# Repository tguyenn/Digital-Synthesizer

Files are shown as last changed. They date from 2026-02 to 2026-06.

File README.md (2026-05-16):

# Imagiano | Digital Synthesizer Project

## $$\color{#CC5500} \text{UT ECE445L Competition Project}$$

Brought to you by...    
[@jeffchang0](https://github.com/jeffchang0)    
[@MorrisYLin](https://github.com/MorrisYLin)    
[@zaarabilal](https://github.com/zaarabilal)    
[@tguyenn](https://github.com/tguyenn)    

## Introduction

We decided to build a digital synthesizer/piano for our final project in UT Austin's Embedded Lab Class! We thought a piano was a great idea since we all love music, and a digital synthesizer presented a good deal of electrical, mechanical, and programming challenges.
  
Our digital piano consists of    
1.) A main controller board  
2.) A series of peripheral boards  
3.) Piano keys with magnets  
4.) Piano enclosure     
    
... all from scratch!  
  
Here's a clip of our project (Rev A) in action, credit to [@jeffchang0](https://github.com/jeffchang0):
> [!IMPORTANT]
> Please <ins>__enable audio__</ins> and applaud the ~~mouth~~camerawork for the full demonstration!  

<p align="center">
  <video src="https://github.com/user-attachments/assets/4a25433e-0272-4781-a5fd-c7f0d65e424b" width="300" controls>
  </video>
</p>

## Table of Contents
1. [System Design](#system-design)
1. [Electrical Design](#electrical-design)
1. [Mechanical Design](#mechanical-design)
1. [Firmware Design](#firmware-design)
1. [Implementation Challenges](#implementation-challenges)
1. [Rev A Credits](#rev-a-credits)
1. [Rev B Motivation and Features](#rev-b-motivation-and-features)

## System Design
Figuring out requirements is by far the most important part of a project! Of course you have to know what you are building before you build it :)

We knew we wanted to make a piano of a larger scale, so we had to figure out how to seamlessly connect a lot of keys together.

After some thinking and debate, we came down to this diagram for our overall system design:    

We opted to have a main controller board daisy-chained with a series of peripheral boards. This main board would also be connected to user interfaces like an LCD, digital rotary encoders, and an addressable LED strip.        

<table>
  <tr>
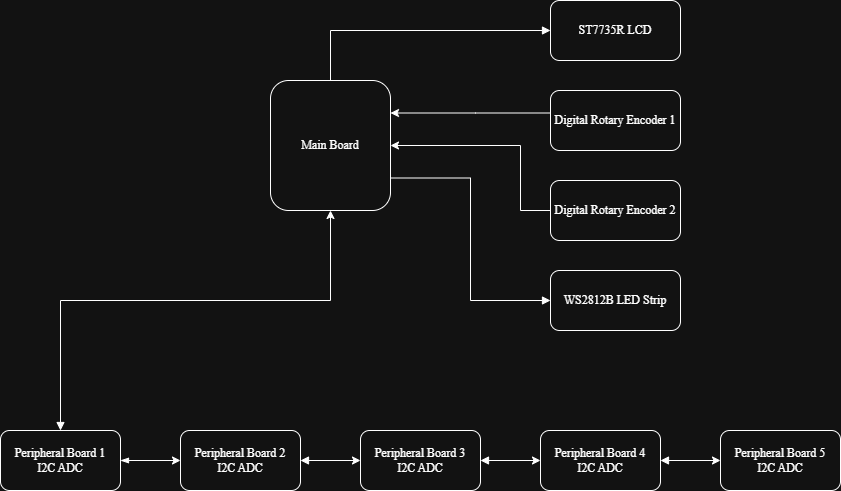
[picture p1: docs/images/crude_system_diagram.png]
system plan diagram
    <td></td>
  </tr>
  <tr>
    <td colspan="1" align="center">
      <em><b></b> System Plan Diagram</em>
    </td>
  </tr>
</table>  
Each peripheral board would have an array of linear Hall effect sensors to determine key position, with 12 of these sensors to form an octave. 5 of these peripheral boards allowed us to cover a good range of pitches!  
       
<table>
  <tr>
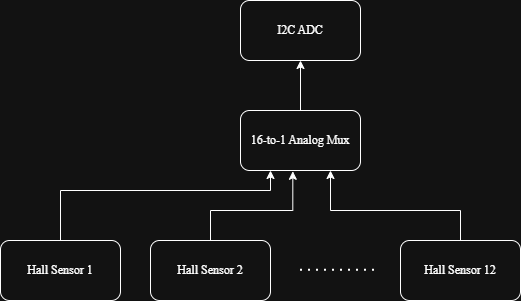
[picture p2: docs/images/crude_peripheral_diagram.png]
periph board diagram
    <td></td>
  </tr>
  <tr>
    <td colspan="1" align="center">
      <em><b></b> Peripheral Board Plan Diagram</em>
    </td>
  </tr>
</table>

To give some insight into what this came to be, here is a picture of our daisy-chained peripheral boards (sharpie for scale):  
<table>
  <tr>
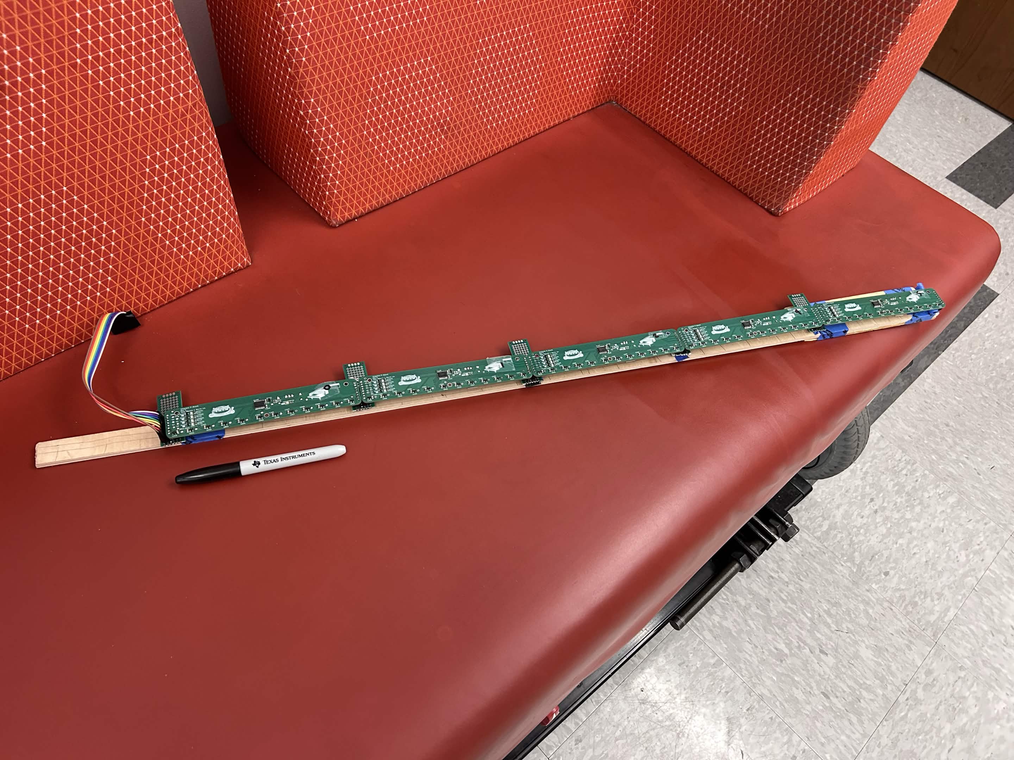
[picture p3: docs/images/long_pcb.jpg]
long pcb
    <td></td>
  </tr>
  <tr>
    <td colspan="1" align="center">
      <em><b></b> Extra Extra Long PCB</em>
    </td>
  </tr>
</table>

## Electrical Design
Once we had planned out the high-level details of the project, it was time to figure out what electrical connections needed to be made. First, it was time to go window shopping and datasheet diving on Mouser to figure out what we were even working with.

Once we had picked out all our parts, we drew out the schematic (and all of the relevant subsheets):    

<table>
  <tr>
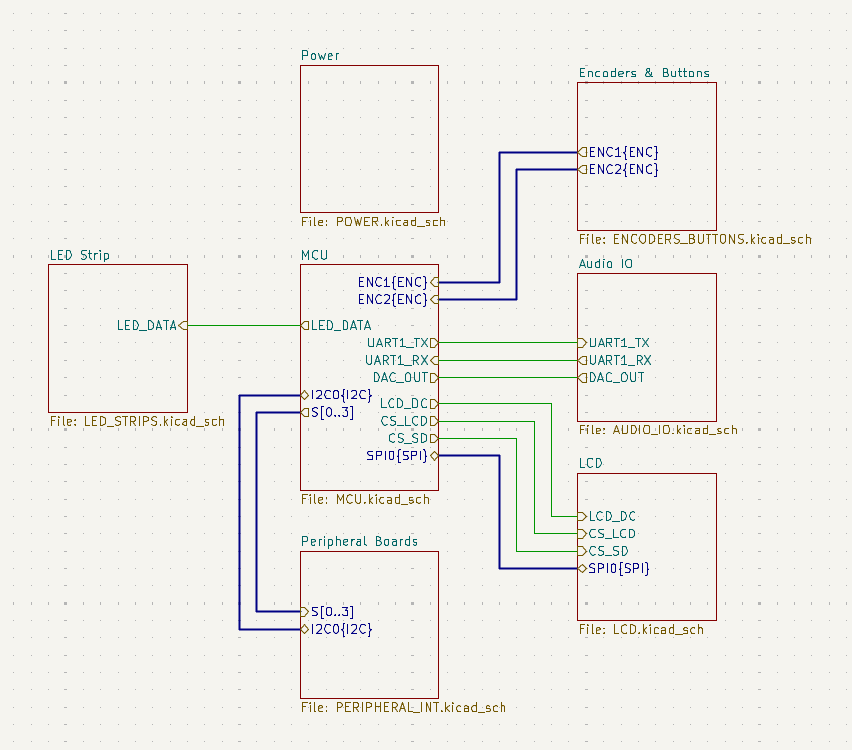
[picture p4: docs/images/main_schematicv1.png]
Main Schematic Rev A
    <td></td>
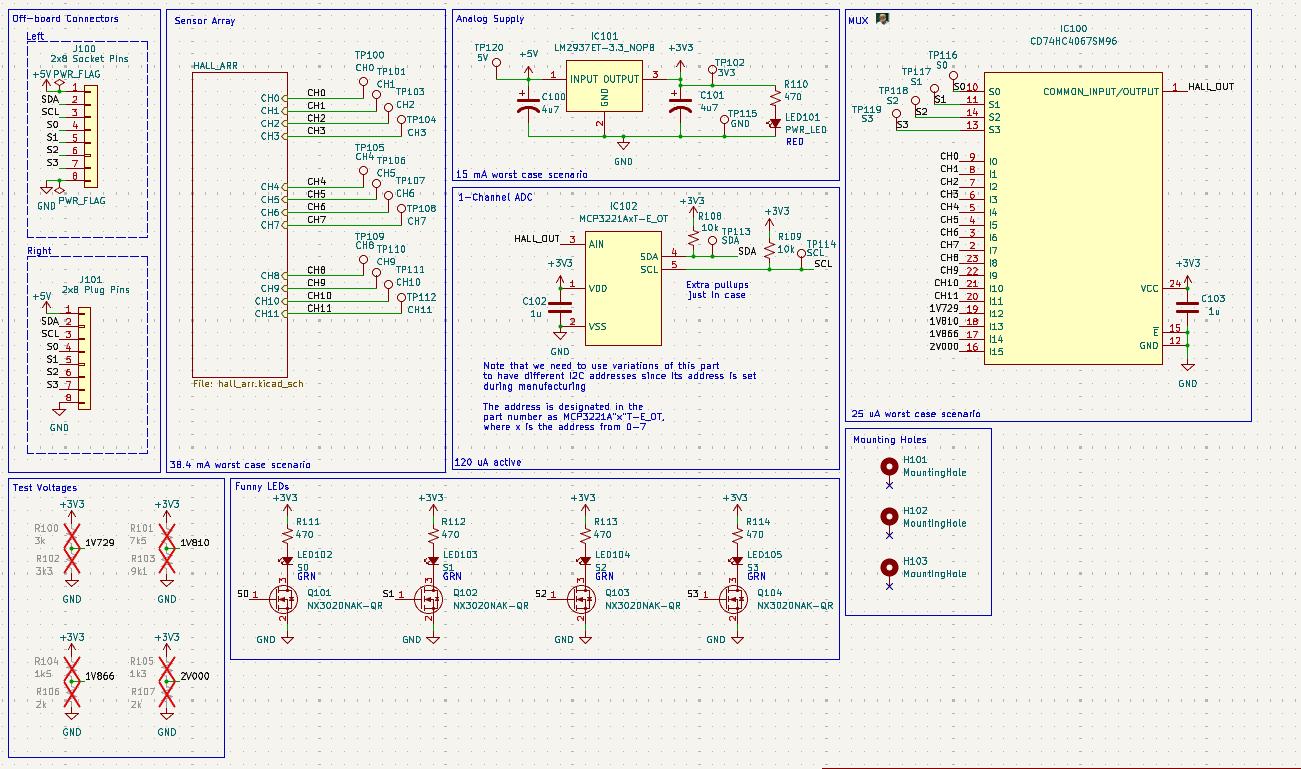
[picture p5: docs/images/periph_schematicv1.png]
Periph Schematic Rev A
    <td></td>
  </tr>
  <tr>
    <td colspan="2" align="center">
      <em><b>Rev A -</b>  Main (Left) and Peripheral (Right) Schematics</em>
    </td>
  </tr>
</table>

After verifying the schematic, we moved onto laying out the PCB itself:
<table>
  <tr>
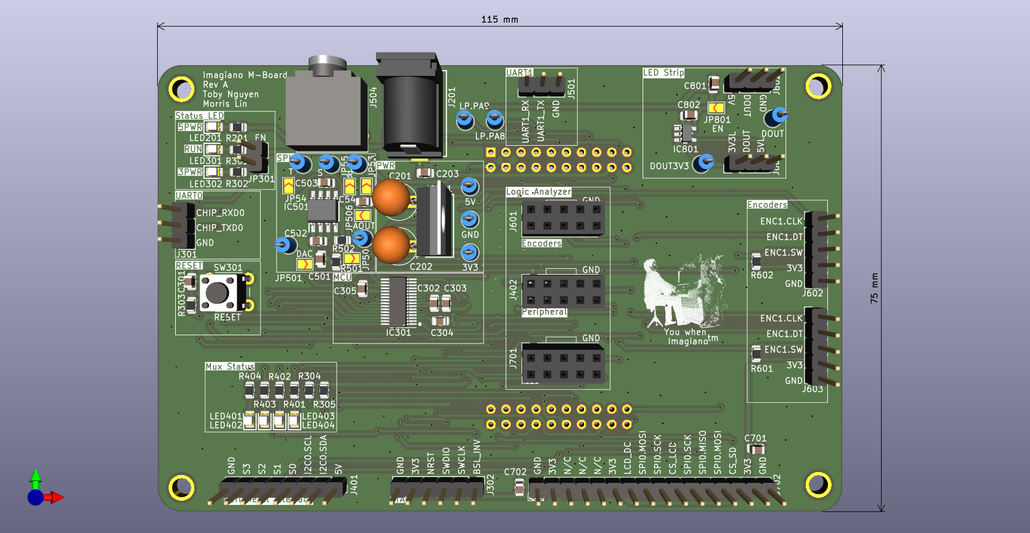
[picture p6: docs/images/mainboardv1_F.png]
    <td></td>
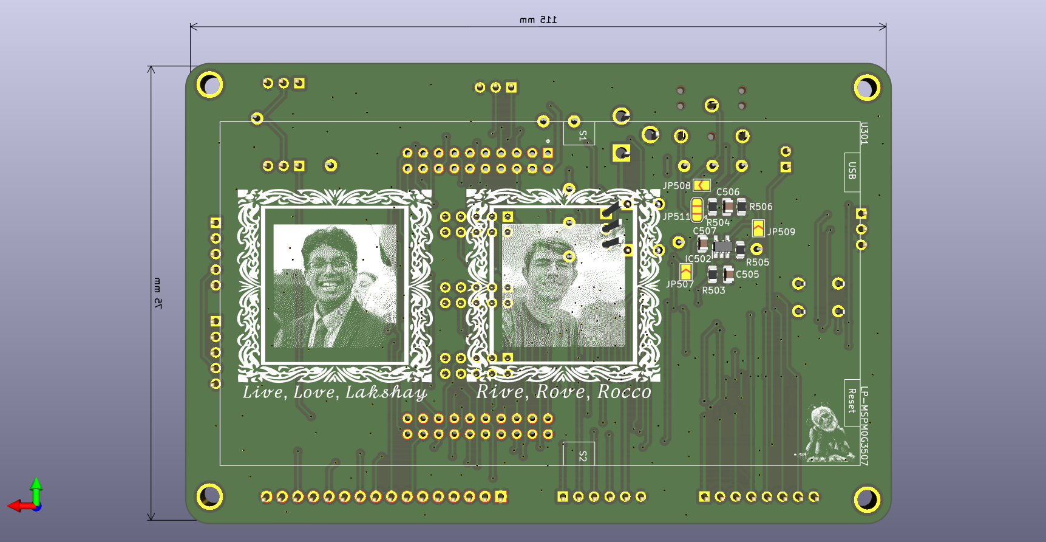
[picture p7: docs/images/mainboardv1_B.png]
    <td></td>
  </tr>
  <tr>
    <td colspan="2" align="center">
      <em><b>Rev A -</b> Front and back main board</em>
    </td>
  </tr>
</table>

<table>
  <tr>
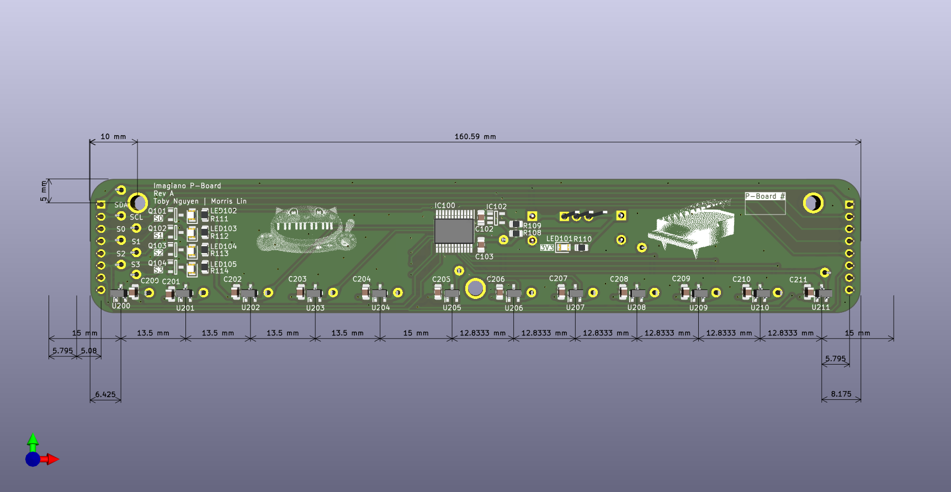
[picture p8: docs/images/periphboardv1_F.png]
    <td></td>
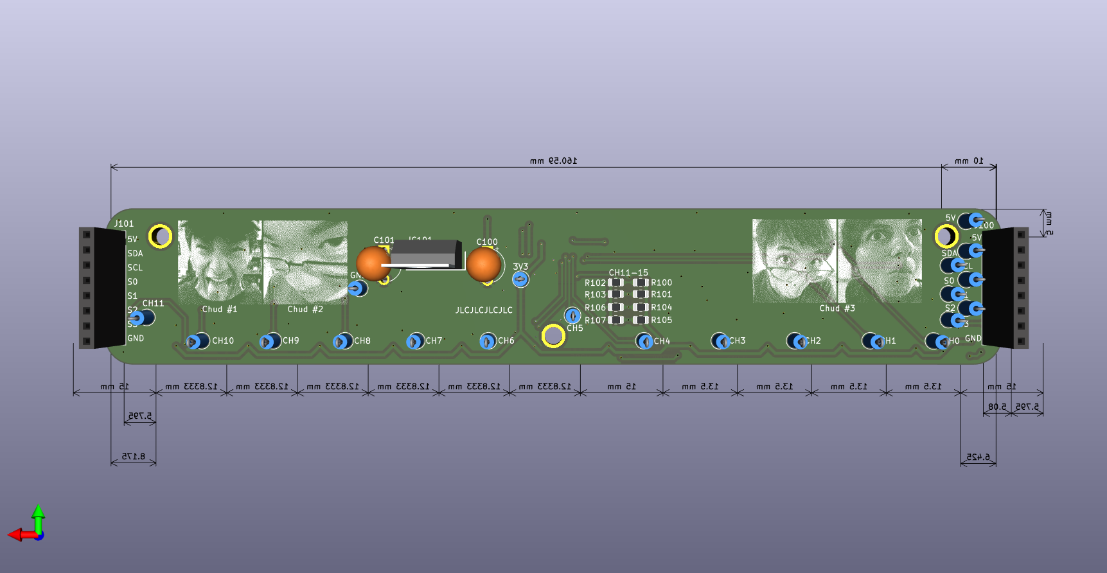
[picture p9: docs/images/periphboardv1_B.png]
    <td></td>
  </tr>
  <tr>
    <td colspan="2" align="center">
      <em><b>Rev A -</b> Front and back peripheral board</em>
    </td>
  </tr>
</table>

### Design Choices
#### Why did you choose Texas Instrument's MSPM0G3507 MCU?
- Since this was a class project, we were required to use this particular MCU.

#### Why did you use an MSPM0G3507 launchpad/devkit instead of having two discrete MCUs?
- Since this was a class project, we were required to have a fallback plan in case our discrete MCU did not work for any reason.  

#### Why did you choose I2C over SPI for the wired peripheral board bus?
- At first we were going to go with an SPI bus connected as a "star topology" vs daisy-chained. We ultimately went with I2C to reduce the amount of GPIO usage and wires (i.e. SPI CS line for every peripheral board -> just the I2C SDA & SCL). We did consider the possible issue of bus capacitance since our bus would be almost a meter long (!!), but we just accepted our fate (reduce I2C speed if necessary).  

#### Why is there an LDO on every peripheral board?
- Instead of routing 3V3 all across each peripheral board, we opted to route 5V and have local 3V3 LDOs. This removed any possibility of power supply noise within our sensitive analog Hall sensors.  

#### Why do we have LEDs on the analog mux select lines?
- For fun! It's also nice to have a visual indicator when debugging (i.e. which sensor index is being sampled right at this moment when I pause?)  

#### Why did you use a mix of through hole components (LDO, capacitors) or other non-ideal components (speaker amp)?
- Since this was a class project, we were restricted to a very stringent budget ($60!) for the entire project. The through hole components and speaker amp were considered "free" since we could get them from a university equipment desk.    

#### Why did you use funny protoboards as connectors instead of using right angle connectors?
- Same thing as above. Right angle connectors would be the way to go, but the budget limitations said otherwise.    
  
#### Why did you choose a 2 layer PCB?
- 4 layers would be overkill for this project since board density wasn't crazy. This was also a school project, so we didn't need to worry about EMC regulations (RIP ground plane) and had to worry more about the budget.

#### What happened for your speaker output circuit?
- At the last minute (literally like an hour before designs were due) we realized our original amp design could potentially not work (slipped through team and TA design review), so we slapped on a backup circuit (simple voltage buffer) on the other side. The particular issue was our questionable adaptation of a (free!) differential amplifier for a single ended application.

## Mechanical Design

TODO: @jeffchang0 cad models pictures?

TODO: @jeffchang0 mechanical design challenges

TODO: talk about mass manufacturing of keys
    - shoutout "tiw"

## Firmware Design

TODO: @MorrisYLin @zaarabilal pls
talk about what modules we were to use, drivers we had to make, coding practices, etc

### ADC Sampling
### DSP
### LCD/Encoders
### LED Strip
- WS2812B LED Strip off of [Amazon](https://www.amazon.com/gp/product/B088BPGMXB/ref=ox_sc_act_title_1?smid=A35UAT07QG3EC6&th=1)
- We used PWM via the TimerG7 and the DMA controller to create the data stream for the finicky LED strip protocol.
  1. Defined the period the PWM waveform to be 1.25 µs and adjusted the duty cycle to transmit a `0` or `1`
  1. TimerG7 configured to publish a `Generic Event 0` to `Event Channel 1` every time the counter reached its reload point
  1. The DMA controller subscribed to this channel executed a Repeat Single Transfer upon each trigger to move a duty cycle value from a buffer into the TimerG7 CC01 register

## Implementation Challenges
- There were a few small (but important!) details that slipped through PCB design review, namely
    - Pinout for onboard MSPM0 MCU footprint was flipped on one rail, so many pins had to be bluewired for the onboard MCU to work
    - Pinout for dc barrel jack was also wrong (ground plane became a 5V plane), so had to desolder and use a flying screw terminal setup
    - Pulled reset pin to the wrong polarity (nReset to ground), so we had to cut the trace and let the internal pullup do its thing
- Jumper pains
    - During testing, we could not get the I2C module to output from our MSPM0 devkit pins. This was especially unfortunate and took us two hours to realize we had to remove some configuration jumpers on the devkit.
- Magnets in the keys
    - We initially tried putting all the key magnets facing the same direction, but they kept interfering with each other (pressing one key also pressed adjacent keys)
    - We had to alternate the magnet polarity and fix in software (linear Hall sensors output voltage swinging in the opposite direction)
- DSP calculations took so much CPU time that no other peripherals besides ADC sampling worked
    - Had to reduce scope of project (removed user interface) to meet the deadline with a working product
- Competition restricted us to writing everything without using TI's beloved SysConfig, so we had to figure out some module initializations by ourselves using the datasheet + TRM
- BOM management
    - Sticking to the $60 budget for the entire project was tricky, and we had to cut corners wherever possible

## Rev A Credits
[@jeffchang0](https://github.com/jeffchang0) - Mechanical design/fabrication    
[@MorrisYLin](https://github.com/MorrisYLin) - DAC driver/firmware, DSP firmware, PCB design/validation    
[@zaarabilal](https://github.com/zaarabilal) - I2C ADC driver/firmware, LCD/digital encoder drivers/firmware, Mechanical design    
[@tguyenn](https://github.com/tguyenn) - PCB design/validation/assembly, WS2812B LED driver/firmware, Documentation

## Rev B Motivation and Features
Due to time and budget restrictions, we weren't able to cleanly implement all of our features. We didn't like that, so we decided to spin a new revision of the main board to add and fix some features.

Some of these features include:
- Replaced MSPM0G3507 with dual core microcontroller (RP2040) to properly handle the math compute load, sound output, LED strip output, and user interface
  - Dual-core instead of two discrete MCUs because flashing twice and maintaining two codebases is annoying
- 4 layer PCB
- Removed backpack devkit
  - Escape potential jumper hell
- Cleaned audio output circuit
- Replaced all through-hole with SMD components
- Replace main board LDO with switching regulator for fun
- Black soldermask + ENIG PCBs
- Silkscreen art!
- added ESD protection ???

<table>
  <tr>
    <td>Main Schematic Rev B</td>
    <td>Periph Schematic Rev B</td>
  </tr>
  <tr>
    <td colspan="2" align="center">
      <em><b>Rev B -</b>  Main (Left) and Peripheral (Right) Schematics</em>
    </td>
  </tr>
</table>

After verifying the schematic, we moved onto laying out the PCB itself:
<table>
  <tr>
    <td>Front</td>
    <td>Back</td>
  </tr>
  <tr>
    <td colspan="2" align="center">
      <em><b>Rev B -</b> Front and back main board</em>
    </td>
  </tr>
</table>

<table>
  <tr>
    <td>Front</td>
    <td>Back</td>
  </tr>
  <tr>
    <td colspan="2" align="center">
      <em><b>Rev B -</b> Front and back peripheral board</em>
    </td>
  </tr>
</table>

coming soon...™️ 

## Rev B Electrical Design
## Rev B Credits

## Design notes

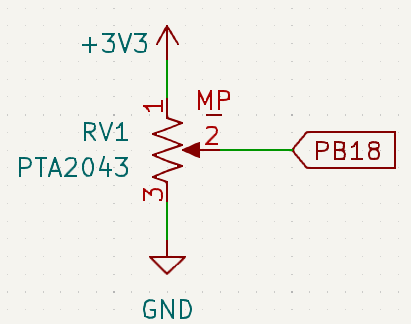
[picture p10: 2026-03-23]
firmware/firmware_v1/Launchpad/Lab7Circuit.png

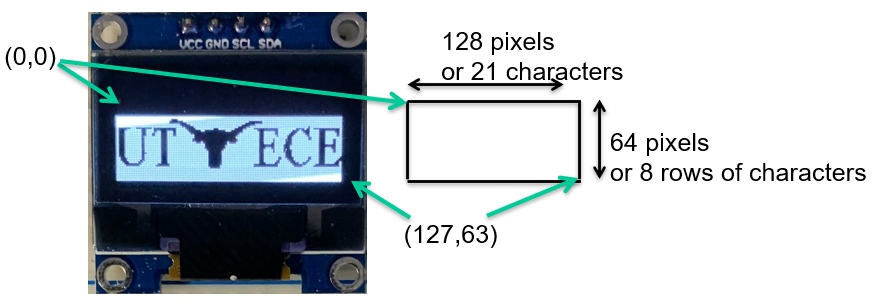
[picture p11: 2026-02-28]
firmware/firmware_v1/inc/SSD1306.png

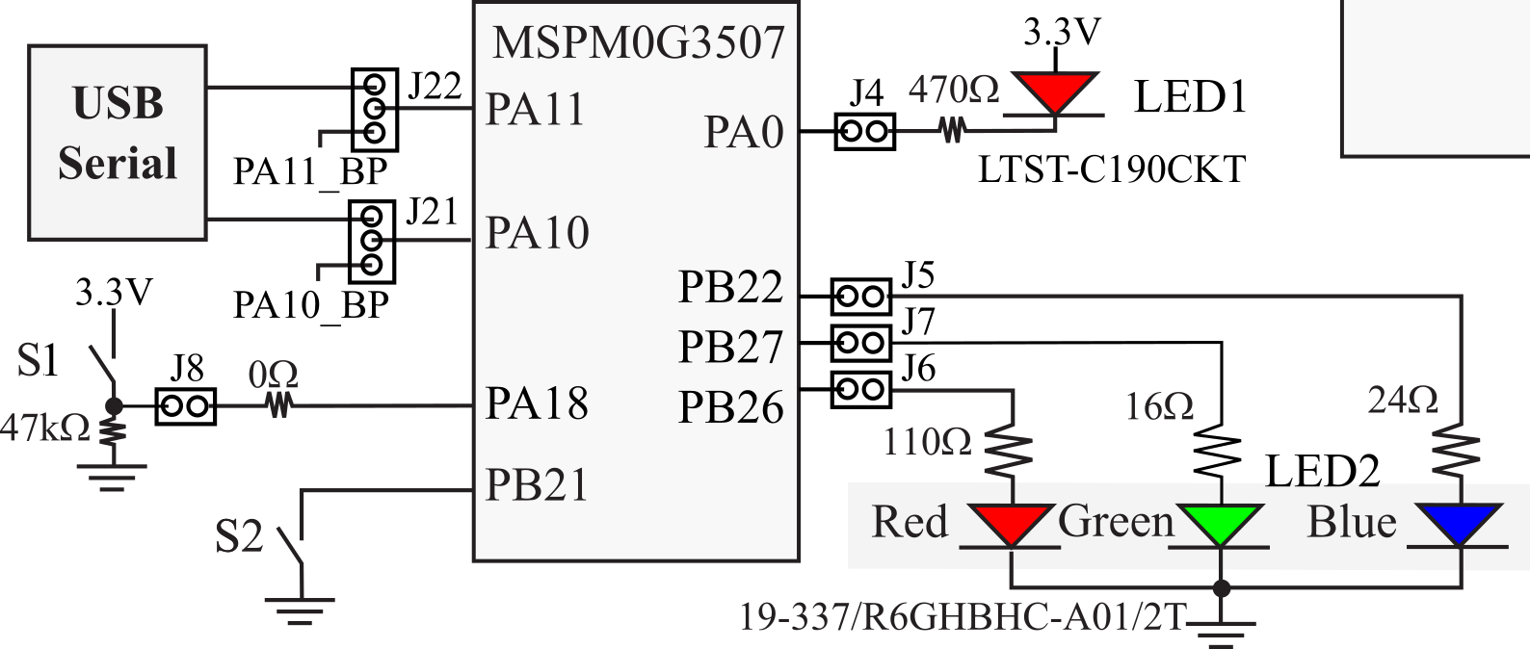
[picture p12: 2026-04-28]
firmware/firmware_v1/inc/LaunchPad.png

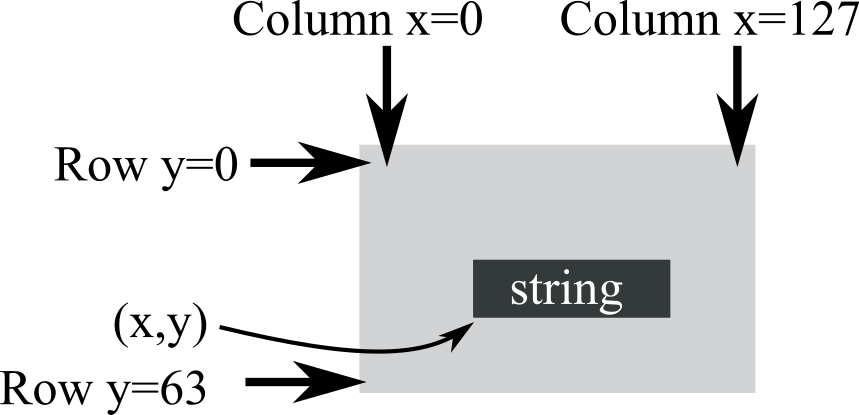
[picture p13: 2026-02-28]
firmware/firmware_v1/inc/SSD1306DrawString.png

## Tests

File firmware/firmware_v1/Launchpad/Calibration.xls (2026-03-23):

 | Do this calibration yourself
 | y | x | x^2 | x*y
 | Position (0.001 cm) | ADC Data |  |  | Fitted Position (0.001cm) | Error | percent
 | 100 | 538 | 289444 | 53800 | 84 | -0.016 | 1.60%
 | 400 | 1295 | 1677025 | 518000 | 421 | 0.021 | 2.10%
 | 800 | 2140 | 4579600 | 1712000 | 798 | -0.002 | 0.20%
 | 1200 | 3050 | 9302500 | 3660000 | 1203 | 0.003 | 0.30%
 | 1400 | 3474 | 12068676 | 4863600 | 1392 | -0.008 | 0.80%
Sum | 3900 | 10497 | 27917245 | 10807400
 | n | 5 |  |  |  | Ave | 1.00%
 | m | 0.4455458948
 | b | -155.3790516
 | 12 bit | 4096
 | k1 | 1825
 | k2 | -155

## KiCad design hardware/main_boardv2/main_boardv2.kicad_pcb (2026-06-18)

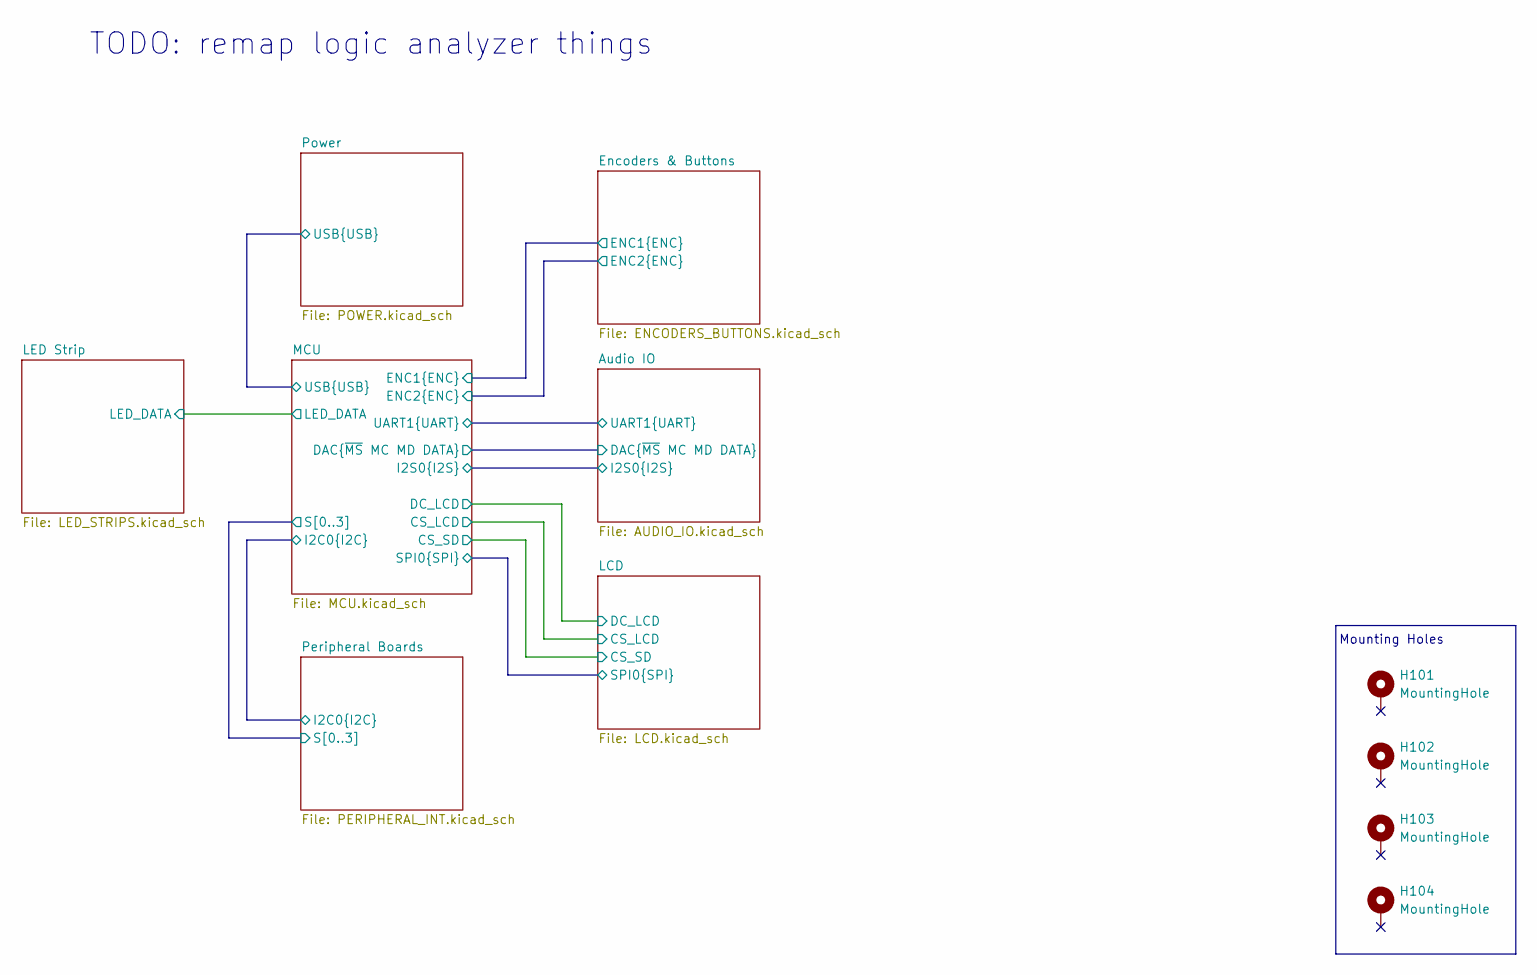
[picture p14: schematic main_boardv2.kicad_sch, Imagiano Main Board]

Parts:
H101, H102, H103, H104: MountingHole; standoff_MH

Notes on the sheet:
Mounting Holes
TODO: remap logic analyzer things

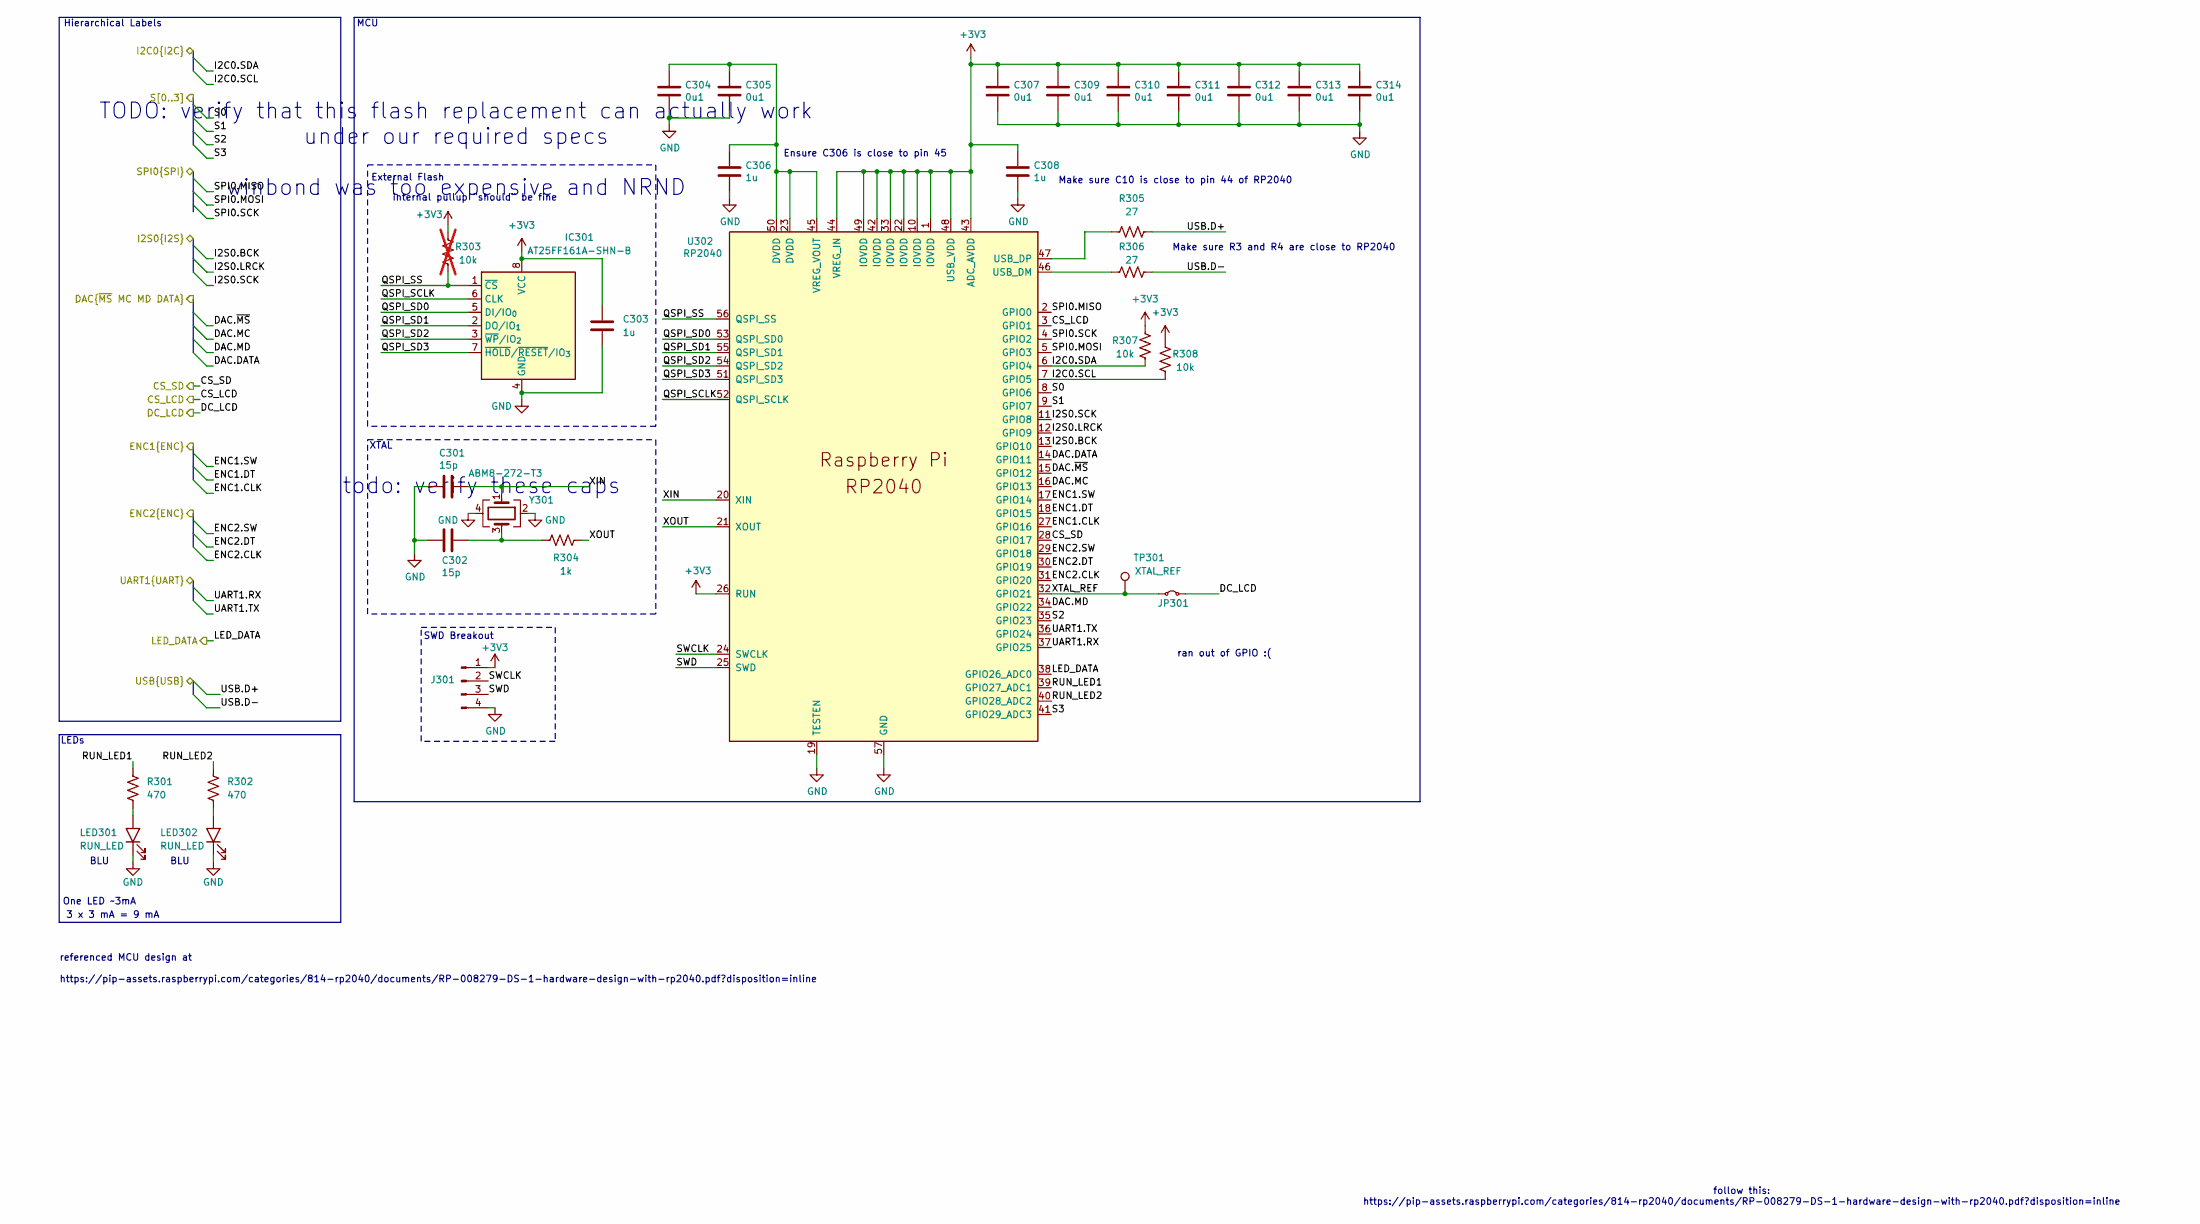
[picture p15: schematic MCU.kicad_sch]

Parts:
C301, C302: 15p; C_0603_1608Metric
C303, C306, C308: 1u; C_0603_1608Metric
C304, C305, C307, C309, C310, C311, C312, C313, C314: 0u1; C_0603_1608Metric
IC301: AT25FF161A-SHN-B; SOIC127P798X216-8N; Manufacturer_Part_Number AT25FF161A-SHN-B
J301: SWD Breakout; PinHeader_1x04_P2.54mm_Vertical
JP301: Jumper_2_Small_Bridged; SolderJumper-2_P1.3mm_Bridged2Bar_RoundedPad1.0x1.5mm
LED301, LED302: RUN_LED; LEDC2012X40N; Mouser Part Number 720-LSR976-NR-1
R301, R302: 470; R_0603_1608Metric
R303: 10k; R_0603_1608Metric; not fitted
R304: 1k; R_0603_1608Metric
R305, R306: 27; R_0603_1608Metric
R307, R308: 10k; R_0603_1608Metric
TP301: XTAL_REF; bettertestpoint2
U302: RP2040; SC091413
Y301: ABM8-272-T3; Crystal_SMD_3225-4Pin_3.2x2.5mm

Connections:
+3V3: C303.2, C307.1, C308.1, C309.1, C310.1, C311.1, C312.1, C313.1, C314.1, IC301.8 (VCC), J301.1, R303.2, R307.2, R308.2, U302.1 (IOVDD), U302.10 (IOVDD), U302.22 (IOVDD), U302.26 (RUN), U302.33 (IOVDD), U302.42 (IOVDD), U302.43 (ADC_AVDD), U302.44 (VREG_IN), U302.48 (USB_VDD), U302.49 (IOVDD); also elsewhere on the board
/Audio IO/DAC.DATA: U302.14 (GPIO11); also elsewhere on the board
/Audio IO/DAC.MC: U302.16 (GPIO13); also elsewhere on the board
/Audio IO/DAC.MD: U302.34 (GPIO22); also elsewhere on the board
/Audio IO/DAC.~MS: U302.15 (GPIO12); also elsewhere on the board
/Audio IO/I2S0.BCK: U302.13 (GPIO10); also elsewhere on the board
/Audio IO/I2S0.LRCK: U302.12 (GPIO9); also elsewhere on the board
/Audio IO/I2S0.SCK: U302.11 (GPIO8); also elsewhere on the board
/Audio IO/UART1.RX: U302.37 (GPIO25); also elsewhere on the board
/Audio IO/UART1.TX: U302.36 (GPIO24); also elsewhere on the board
/Encoders & Buttons/ENC1.CLK: U302.27 (GPIO16); also elsewhere on the board
/Encoders & Buttons/ENC1.DT: U302.18 (GPIO15); also elsewhere on the board
/Encoders & Buttons/ENC1.SW: U302.17 (GPIO14); also elsewhere on the board
/Encoders & Buttons/ENC2.CLK: U302.31 (GPIO20); also elsewhere on the board
/Encoders & Buttons/ENC2.DT: U302.30 (GPIO19); also elsewhere on the board
/Encoders & Buttons/ENC2.SW: U302.29 (GPIO18); also elsewhere on the board
/LCD/CS_LCD: U302.3 (GPIO1); also elsewhere on the board
/LCD/CS_SD: U302.28 (GPIO17); also elsewhere on the board
/LCD/DC_LCD: JP301.2 (B); also elsewhere on the board
/LCD/SPI0.MISO: U302.2 (GPIO0); also elsewhere on the board
/LCD/SPI0.MOSI: U302.5 (GPIO3); also elsewhere on the board
/LCD/SPI0.SCK: U302.4 (GPIO2); also elsewhere on the board
/LED Strip/LED_DATA: U302.38 (GPIO26_ADC0); also elsewhere on the board
/MCU/I2C0.SCL: R308.1, U302.7 (GPIO5); also elsewhere on the board
/MCU/I2C0.SDA: R307.1, U302.6 (GPIO4); also elsewhere on the board
/MCU/QSPI_SCLK: IC301.6 (CLK), U302.52 (QSPI_SCLK)
/MCU/QSPI_SD0: IC301.5 (DI/IO_{0}), U302.53 (QSPI_SD0)
/MCU/QSPI_SD1: IC301.2 (DO/IO_{1}), U302.55 (QSPI_SD1)
/MCU/QSPI_SD2: IC301.3 (~WP/IO_{2}), U302.54 (QSPI_SD2)
/MCU/QSPI_SD3: IC301.7 (~HOLD/~RESET/IO_{3}), U302.51 (QSPI_SD3)
/MCU/QSPI_SS: IC301.1 (~CS), R303.1, U302.56 (QSPI_SS)
/MCU/RUN_LED1: R301.1, U302.39 (GPIO27_ADC1)
/MCU/RUN_LED2: R302.1, U302.40 (GPIO28_ADC2)
/MCU/S0: U302.8 (GPIO6); also elsewhere on the board
/MCU/S1: U302.9 (GPIO7); also elsewhere on the board
/MCU/S2: U302.35 (GPIO23); also elsewhere on the board
/MCU/S3: U302.41 (GPIO29_ADC3); also elsewhere on the board
/MCU/SWCLK: J301.2, U302.24 (SWCLK)
/MCU/SWD: J301.3, U302.25 (SWD)
/MCU/USB.D+: R305.2; also elsewhere on the board
/MCU/USB.D-: R306.2; also elsewhere on the board
/MCU/XIN: C301.1, U302.20 (XIN), Y301.1
/MCU/XOUT: R304.2, U302.21 (XOUT)
/MCU/XTAL_REF: JP301.1 (A), TP301.1, U302.32 (GPIO21)
GND: C301.2, C302.2, C303.1, C304.2, C305.2, C306.2, C307.2, C308.2, C309.2, C310.2, C311.2, C312.2, C313.2, C314.2, IC301.4 (GND), J301.4, LED301.1 (K), LED302.1 (K), U302.19 (TESTEN), U302.57 (GND), Y301.2, Y301.4; also elsewhere on the board
unnamed: C302.1, R304.1, Y301.3
unnamed: LED301.2 (A), R301.2
unnamed: LED302.2 (A), R302.2
unnamed: R306.1, U302.46 (USB_DM)
unnamed: R305.1, U302.47 (USB_DP)
unnamed: C304.1, C305.1, C306.1, U302.23 (DVDD), U302.45 (VREG_VOUT), U302.50 (DVDD)

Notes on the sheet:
MCU
TODO: verify that this flash replacement can actually work under our required specs winbond was too expensive and NRND
referenced MCU design at https://pip-assets.raspberrypi.com/categories/814-rp2040/documents/RP-008279-DS-1-hardware-design-with-rp2040.pdf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
LEDs
BLU
SWD Breakout
Ensure C306 is close to pin 45
ran out of GPIO :(
Hierarchical Labels
todo: verify these caps
follow this: https://pip-assets.raspberrypi.com/categories/814-rp2040/documents/RP-008279-DS-1-hardware-design-with-rp2040.pdf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
XTAL
External Flash
Make sure R3 and R4 are close to RP2040
Make sure C10 is close to pin 44 of RP2040
internal pullup "should" be fine
One LED ~3mA
3 x 3 mA = 9 mA

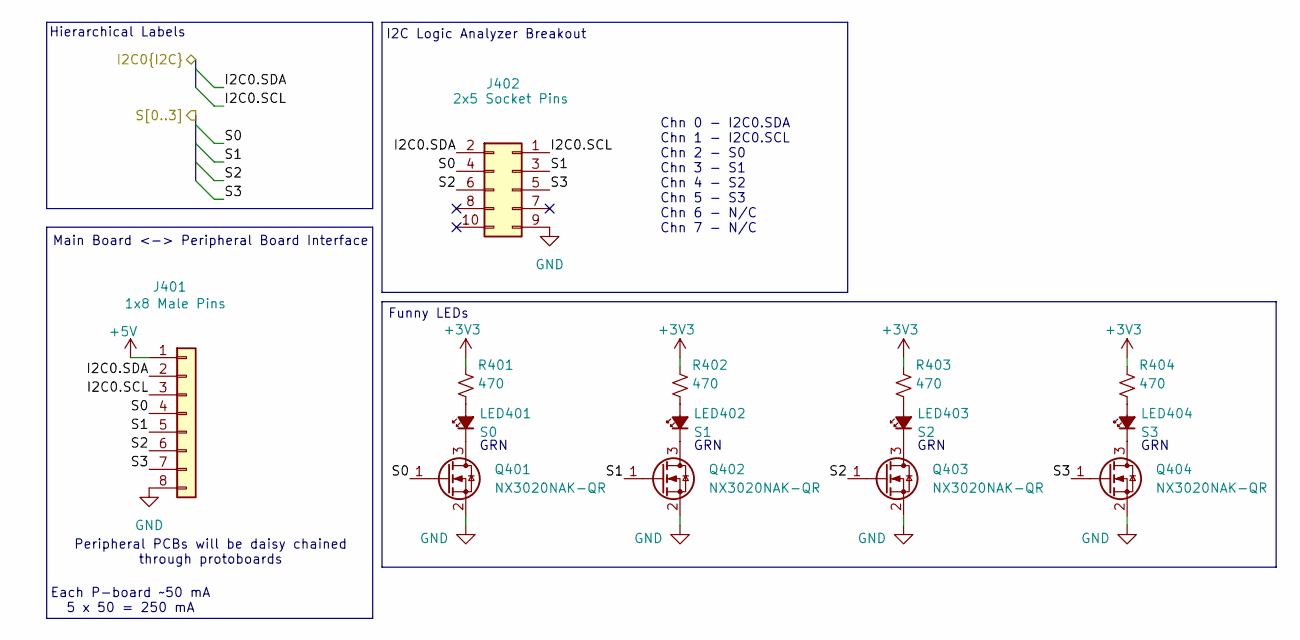
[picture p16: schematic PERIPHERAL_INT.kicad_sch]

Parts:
J401: 1x8 Male Pins; PinSocket_1x08_P2.54mm_Vertical
J402: 2x5 Socket Pins; logic_analyzer_slot_2x5_2.54mm
LED401: S0; LEDC2012X40N; Mouser Part Number 720-LSR976-NR-1
LED402: S1; LEDC2012X40N; Mouser Part Number 720-LSR976-NR-1
LED403: S2; LEDC2012X40N; Mouser Part Number 720-LSR976-NR-1
LED404: S3; LEDC2012X40N; Mouser Part Number 720-LSR976-NR-1
Q401, Q402, Q403, Q404: NX3020NAK-QR; SOT95P230X110-3N; Manufacturer_Part_Number NX3020NAK-QR
R401, R402, R403, R404: 470; R_0603_1608Metric

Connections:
+3V3: R401.2, R402.2, R403.2, R404.2; also elsewhere on the board
+5V: J401.1; also elsewhere on the board
/MCU/I2C0.SCL: J401.3, J402.1; also elsewhere on the board
/MCU/I2C0.SDA: J401.2, J402.2; also elsewhere on the board
/MCU/S0: J401.4, J402.4, Q401.1 (G); also elsewhere on the board
/MCU/S1: J401.5, J402.3, Q402.1 (G); also elsewhere on the board
/MCU/S2: J401.6, J402.6, Q403.1 (G); also elsewhere on the board
/MCU/S3: J401.7, J402.5, Q404.1 (G); also elsewhere on the board
GND: J401.8, J402.9, Q401.2 (S), Q402.2 (S), Q403.2 (S), Q404.2 (S); also elsewhere on the board
unnamed: LED401.2 (A), R401.1
unnamed: LED401.1 (K), Q401.3 (D)
unnamed: LED402.2 (A), R402.1
unnamed: LED402.1 (K), Q402.3 (D)
unnamed: LED403.2 (A), R403.1
unnamed: LED403.1 (K), Q403.3 (D)
unnamed: LED404.2 (A), R404.1
unnamed: LED404.1 (K), Q404.3 (D)

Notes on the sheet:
GRN
Hierarchical Labels
Peripheral PCBs will be daisy chained through protoboards
Funny LEDs
Main Board <-> Peripheral Board Interface
I2C Logic Analyzer Breakout
Chn 0 - I2C0.SDA Chn 1 - I2C0.SCL Chn 2 - S0 Chn 3 - S1 Chn 4 - S2 Chn 5 - S3 Chn 6 - N/C Chn 7 - N/C
Each P-board ~50 mA 5 x 50 = 250 mA

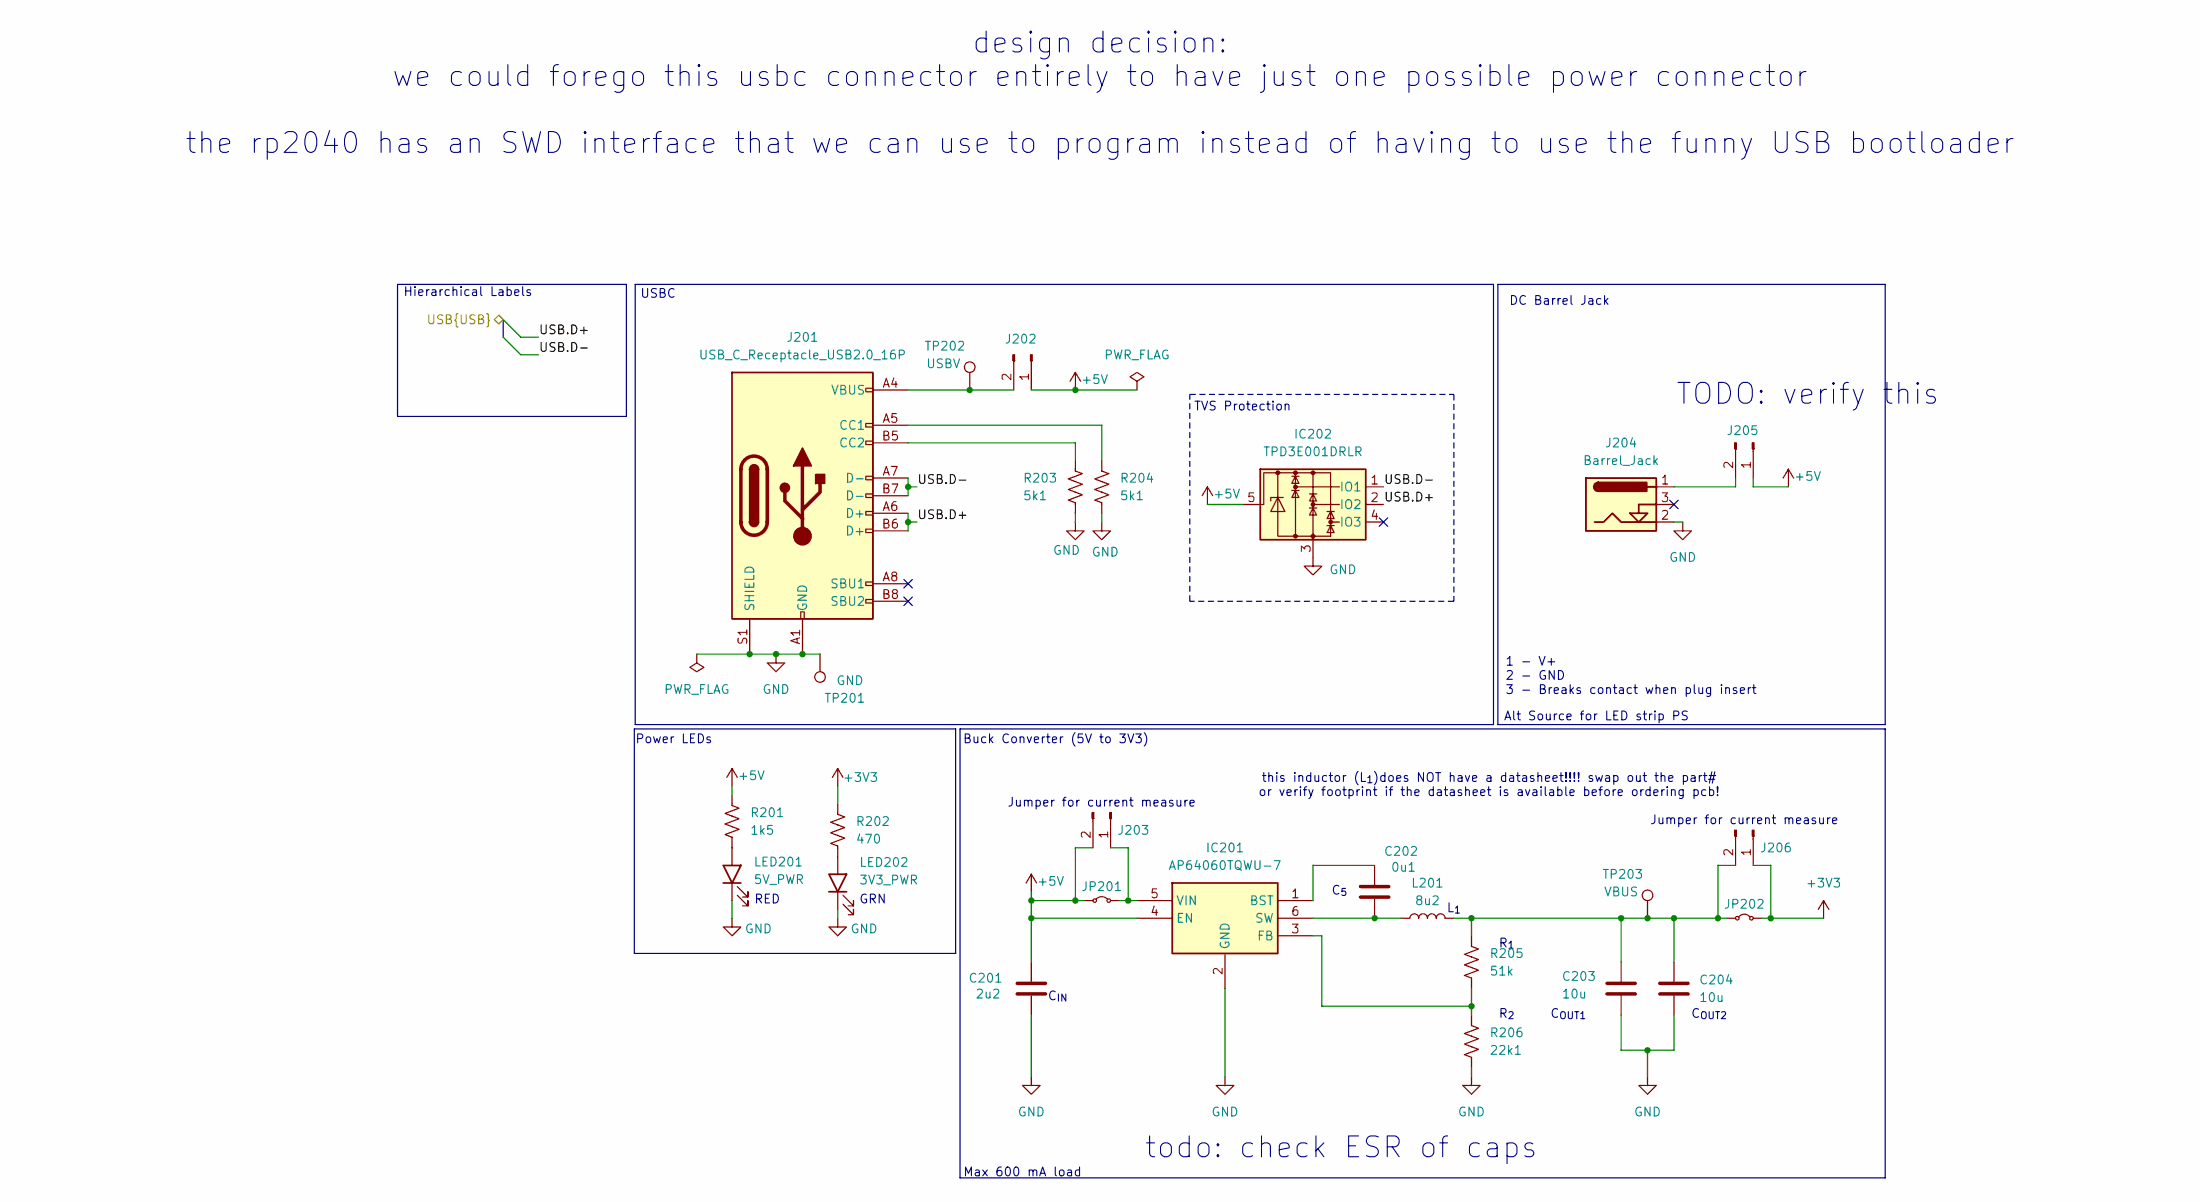
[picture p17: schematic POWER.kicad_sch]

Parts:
C201: 2u2; C_0603_1608Metric
C202: 0u1; C_0603_1608Metric
C203, C204: 10u; C_0603_1608Metric
IC201: AP64060TQWU-7; SOT95P280X100-6N; Manufacturer_Part_Number AP64060TQWU-7
IC202: TPD3E001DRLR; SOTFL50P160X60-5N; Mouser Part Number 595-TPD3E001DRLR
J201: USB_C_Receptacle_USB2.0_16P; USB_C_Receptacle_GCT_USB4105-xx-A_16P_TopMnt_Horizontal
J202, J205: SWD Breakout; PinHeader_1x02_P2.54mm_Vertical
J203, J206: Conn_01x02_Pin; PinHeader_1x02_P2.54mm_Vertical
J204: Barrel_Jack; 373
JP201, JP202: Jumper_2_Small_Bridged; SolderJumper-2_P1.3mm_Bridged2Bar_RoundedPad1.0x1.5mm
L201: 8u2; L_Abracon_ASPI-4030S
LED201: 5V_PWR; LEDC2012X40N; Mouser Part Number 720-LSR976-NR-1
LED202: 3V3_PWR; LEDC2012X40N; Mouser Part Number 720-LSR976-NR-1
R201: 1k5; R_0603_1608Metric
R202: 470; R_0603_1608Metric
R203, R204: 5k1; R_0603_1608Metric
R205: 51k; R_0603_1608Metric
R206: 22k1; R_0603_1608Metric
TP201: GND; bettertestpoint2
TP202: USBV; bettertestpoint2
TP203: VBUS; bettertestpoint2

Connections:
+3V3: J206.1, JP202.2 (B), R202.1; also elsewhere on the board
+5V: C201.2, IC201.4 (EN), IC202.5, J202.1, J203.2, J205.1, JP201.1 (A), R201.1; also elsewhere on the board
/MCU/USB.D+: IC202.2 (IO2), J201.A6 (D+), J201.B6 (D+); also elsewhere on the board
/MCU/USB.D-: IC202.1 (IO1), J201.A7 (D-), J201.B7 (D-); also elsewhere on the board
GND: C201.1, C203.2, C204.2, IC201.2 (GND), IC202.3, J201.A1 (GND), J201.A12 (GND), J201.B1 (GND), J201.B12 (GND), J201.S1 (SHIELD), J204.2, LED201.1 (K), LED202.1 (K), R203.2, R204.2, R206.2, TP201.1; also elsewhere on the board
unnamed: C202.2, IC201.1 (BST)
unnamed: IC201.3 (FB), R205.2, R206.1
unnamed: C202.1, IC201.6 (SW), L201.1
unnamed: IC201.5 (VIN), J203.1, JP201.2 (B)
unnamed: J201.A5 (CC1), R204.1
unnamed: J201.B5 (CC2), R203.1
unnamed: J201.A4 (VBUS), J201.A9 (VBUS), J201.B4 (VBUS), J201.B9 (VBUS), J202.2, TP202.1
unnamed: J204.1, J205.2
unnamed: C203.1, C204.1, J206.2, JP202.1 (A), L201.2, R205.1, TP203.1
unnamed: LED201.2 (A), R201.2
unnamed: LED202.2 (A), R202.2

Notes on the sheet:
Buck Converter (5V to 3V3)
USBC
C_{IN}
R_{1}
C_{OUT2}
Alt Source for LED strip PS
Max 600 mA load
TODO: verify this
GRN
L_{1}
Power LEDs
R_{2}
todo: check ESR of caps
RED
C_{5}
Jumper for current measure
C_{OUT1}
this inductor (L_{1})does NOT have a datasheet!!!! swap out the part# or verify footprint if the datasheet is available before ordering pcb!
1 - V+ 2 - GND 3 - Breaks contact when plug insert
design decision: we could forego this usbc connector entirely to have just one possible power connector the rp2040 has an SWD interface that we can use to program instead of having to use the funny USB bootloader
DC Barrel Jack
Hierarchical Labels
TVS Protection

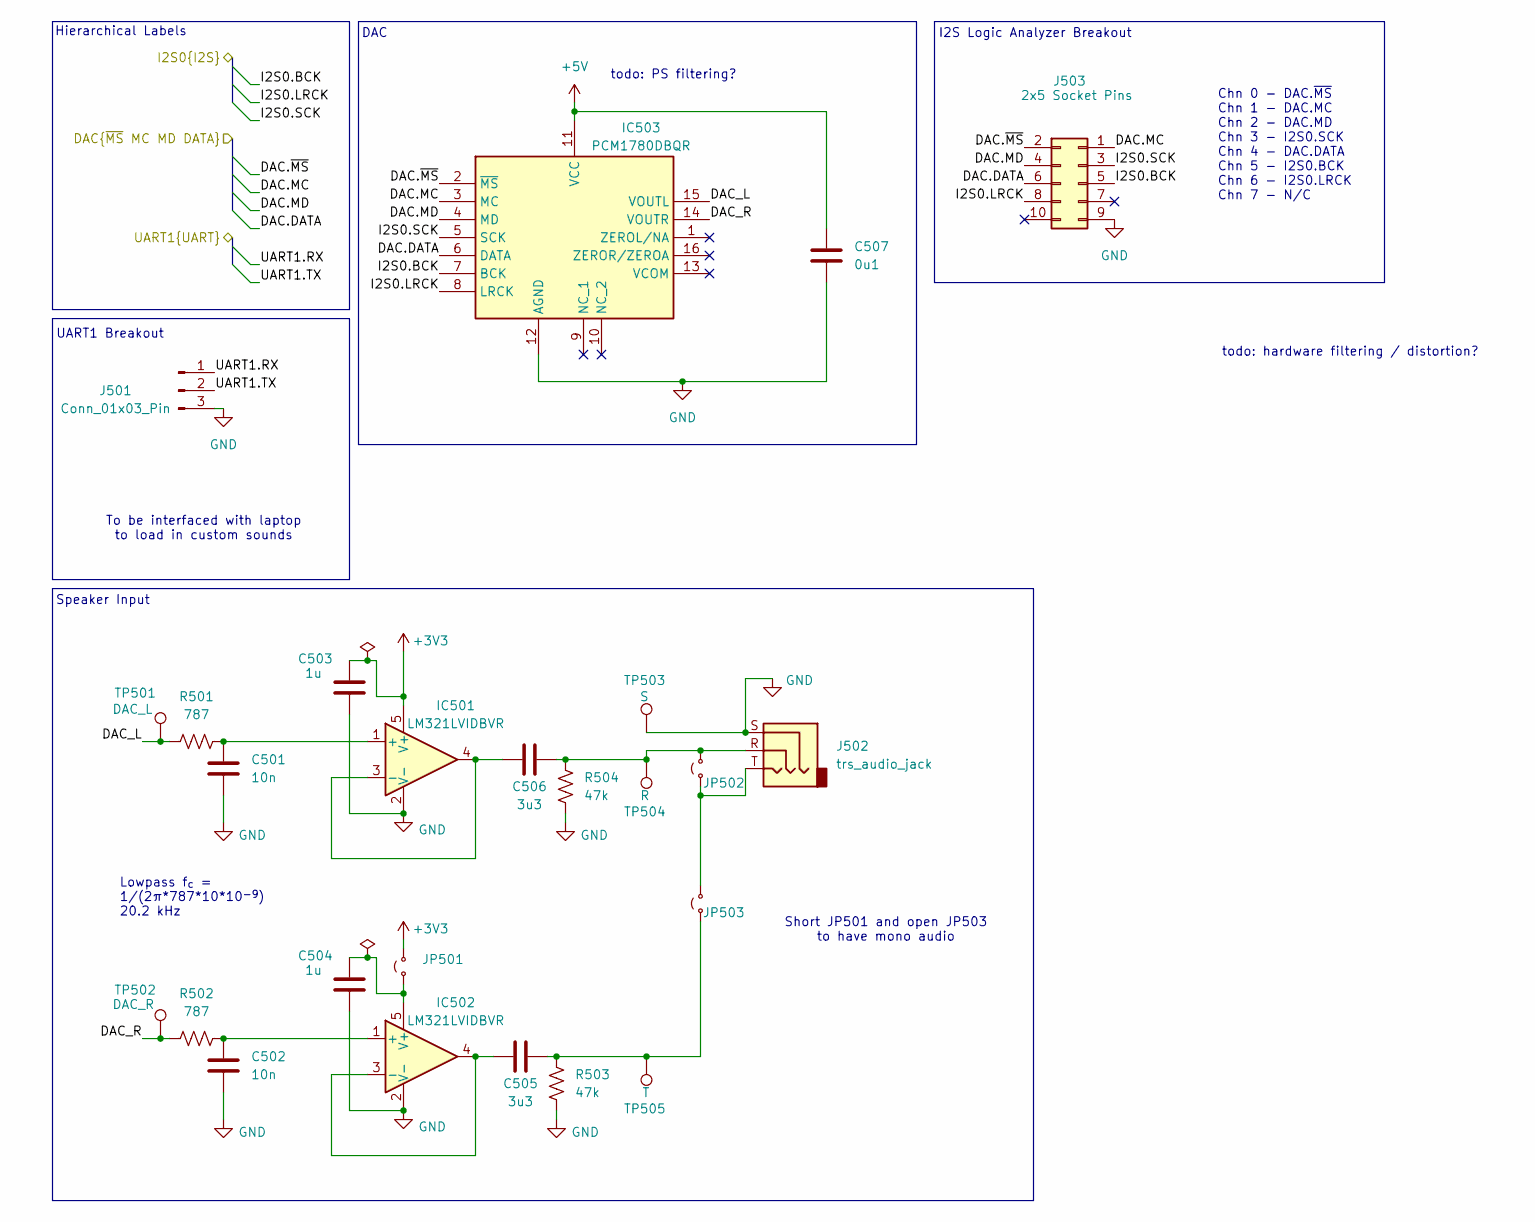
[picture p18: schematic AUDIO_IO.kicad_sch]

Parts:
C501, C502: 10n; C_0603_1608Metric
C503, C504: 1u; C_0603_1608Metric
C505, C506: 3u3; C_0603_1608Metric
C507: 0u1; C_0603_1608Metric
IC501, IC502: LM321LVIDBVR; SOT95P280X145-5N; Mouser Part Number 595-LM321LVIDBVR
IC503: PCM1780DBQR; SOP64P600X175-16N; Mouser Part Number 595-PCM1780DBQR
J501: Conn_01x03_Pin; PinHeader_1x03_P2.54mm_Vertical
J502: trs_audio_jack; Jack_3.5mm_CUI_SJ1-3523N_Horizontal
J503: 2x5 Socket Pins; logic_analyzer_slot_2x5_2.54mm
JP501, JP502, JP503: Jumper_2_Small_Open; SolderJumper-2_P1.3mm_Open_RoundedPad1.0x1.5mm
R501, R502: 787; R_0603_1608Metric
R503, R504: 47k; R_0603_1608Metric
TP501: DAC_L; bettertestpoint2
TP502: DAC_R; bettertestpoint2
TP503: S; bettertestpoint2
TP504: R; bettertestpoint2
TP505: T; bettertestpoint2

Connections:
+3V3: C503.1, IC501.5 (V+), JP501.2 (B); also elsewhere on the board
+5V: C507.2, IC503.11 (VCC); also elsewhere on the board
/Audio IO/DAC.DATA: IC503.6 (DATA), J503.6; also elsewhere on the board
/Audio IO/DAC.MC: IC503.3 (MC), J503.1; also elsewhere on the board
/Audio IO/DAC.MD: IC503.4 (MD), J503.4; also elsewhere on the board
/Audio IO/DAC.~MS: IC503.2 (~MS), J503.2; also elsewhere on the board
/Audio IO/DAC_L: IC503.15 (VOUTL), R501.1, TP501.1
/Audio IO/DAC_R: IC503.14 (VOUTR), R502.1, TP502.1
/Audio IO/I2S0.BCK: IC503.7 (BCK), J503.5; also elsewhere on the board
/Audio IO/I2S0.LRCK: IC503.8 (LRCK), J503.8; also elsewhere on the board
/Audio IO/I2S0.SCK: IC503.5 (SCK), J503.3; also elsewhere on the board
/Audio IO/UART1.RX: J501.1; also elsewhere on the board
/Audio IO/UART1.TX: J501.2; also elsewhere on the board
GND: C501.1, C502.1, C503.2, C504.2, C507.1, IC501.2 (V-), IC502.2 (V-), IC503.12 (AGND), J501.3, J502.S, J503.9, R503.1, R504.1, TP503.1; also elsewhere on the board
unnamed: C501.2, IC501.1 (+), R501.2
unnamed: C506.2, IC501.3 (-), IC501.4
unnamed: C502.2, IC502.1 (+), R502.2
unnamed: C505.2, IC502.3 (-), IC502.4
unnamed: C504.1, IC502.5 (V+), JP501.1 (A)
unnamed: J502.T, JP502.1 (A), JP503.2 (B)
unnamed: C506.1, J502.R, JP502.2 (B), R504.2, TP504.1
unnamed: C505.1, JP503.1 (A), R503.2, TP505.1

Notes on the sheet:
todo: PS filtering?
Lowpass f_{c} = 1/(2π*787*10*10^{-9}) 20.2 kHz
To be interfaced with laptop to load in custom sounds
DAC
UART1 Breakout
Chn 0 - DAC.~{MS} Chn 1 - DAC.MC Chn 2 - DAC.MD Chn 3 - I2S0.SCK Chn 4 - DAC.DATA Chn 5 - I2S0.BCK Chn 6 - I2S0.LRCK Chn 7 - N/C
Short JP501 and open JP503 to have mono audio
I2S Logic Analyzer Breakout
Hierarchical Labels
todo: hardware filtering / distortion?
Speaker Input

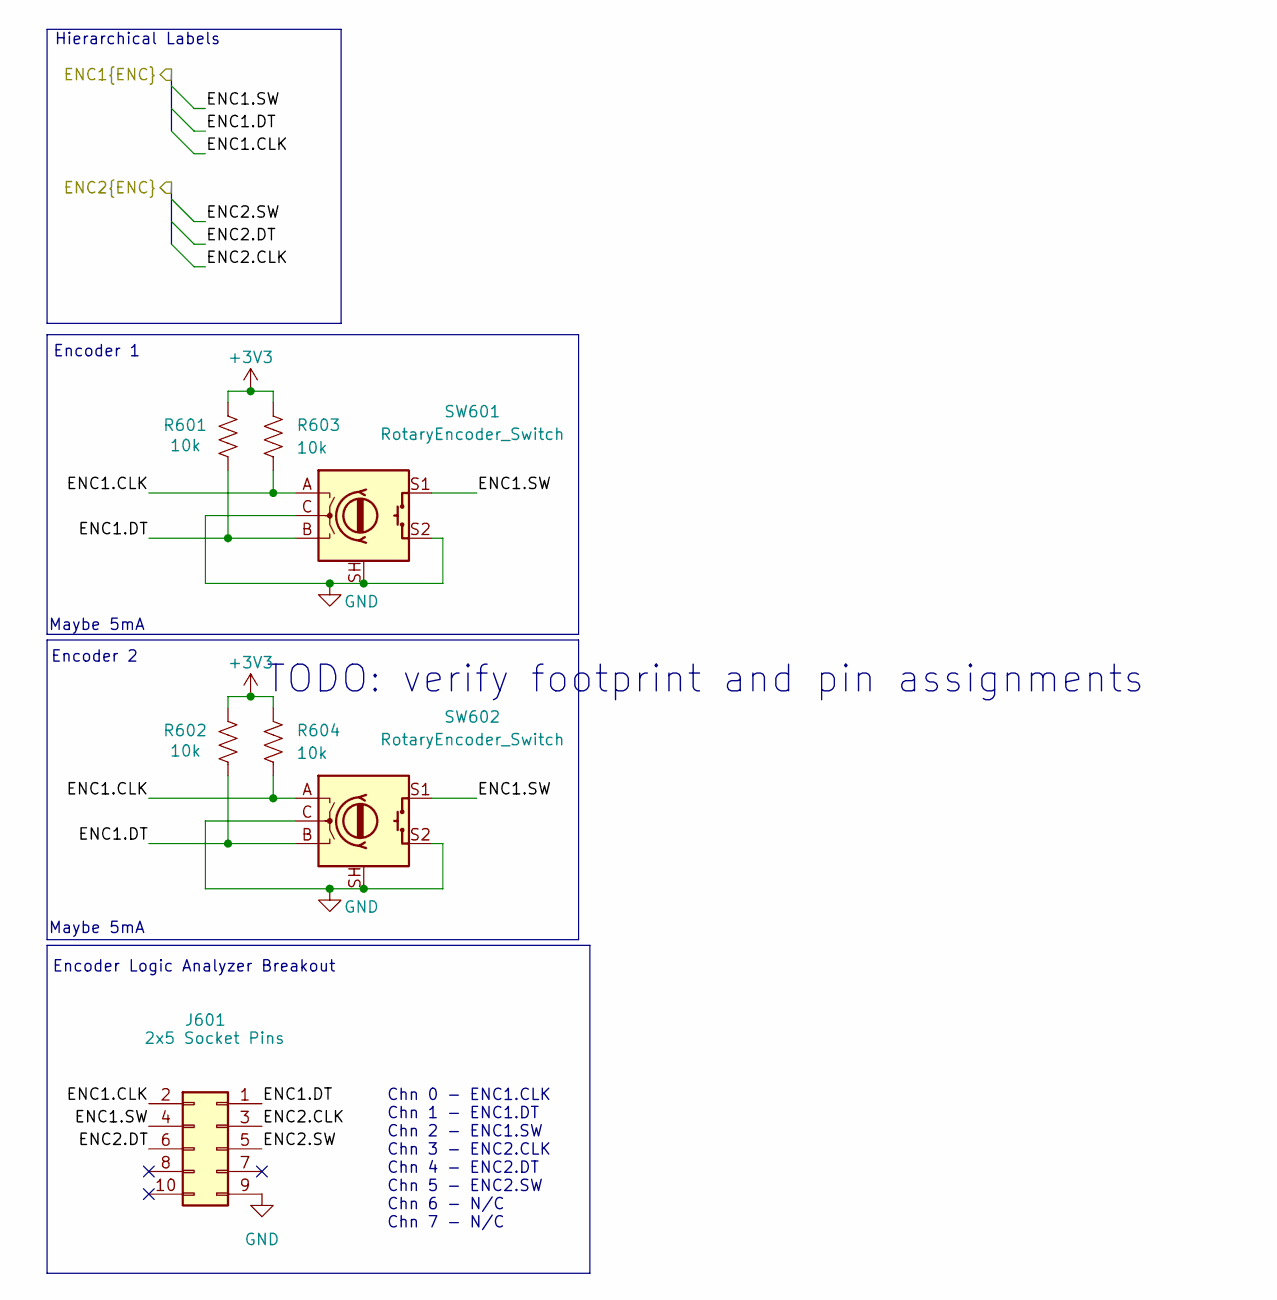
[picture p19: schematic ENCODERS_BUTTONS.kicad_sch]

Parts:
J601: 2x5 Socket Pins; logic_analyzer_slot_2x5_2.54mm
R601, R602, R603, R604: 10k; R_0603_1608Metric
SW601, SW602: RotaryEncoder_Switch; RotaryEncoder_Bourns_Vertical_PEC12R-3x17F-Sxxxx

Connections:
+3V3: R601.2, R602.2, R603.2, R604.2; also elsewhere on the board
/Encoders & Buttons/ENC1.CLK: J601.2, R603.1, R604.1, SW601.A, SW602.A; also elsewhere on the board
/Encoders & Buttons/ENC1.DT: J601.1, R601.1, R602.1, SW601.B, SW602.B; also elsewhere on the board
/Encoders & Buttons/ENC1.SW: J601.4, SW601.S1, SW602.S1; also elsewhere on the board
/Encoders & Buttons/ENC2.CLK: J601.3; also elsewhere on the board
/Encoders & Buttons/ENC2.DT: J601.6; also elsewhere on the board
/Encoders & Buttons/ENC2.SW: J601.5; also elsewhere on the board
GND: J601.9, SW601.C, SW601.S2, SW601.SH, SW602.C, SW602.S2, SW602.SH; also elsewhere on the board

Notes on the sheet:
TODO: verify footprint and pin assignments
Maybe 5mA
Chn 0 - ENC1.CLK Chn 1 - ENC1.DT Chn 2 - ENC1.SW Chn 3 - ENC2.CLK Chn 4 - ENC2.DT Chn 5 - ENC2.SW Chn 6 - N/C Chn 7 - N/C
Encoder Logic Analyzer Breakout
Encoder 1
Encoder 2
Hierarchical Labels

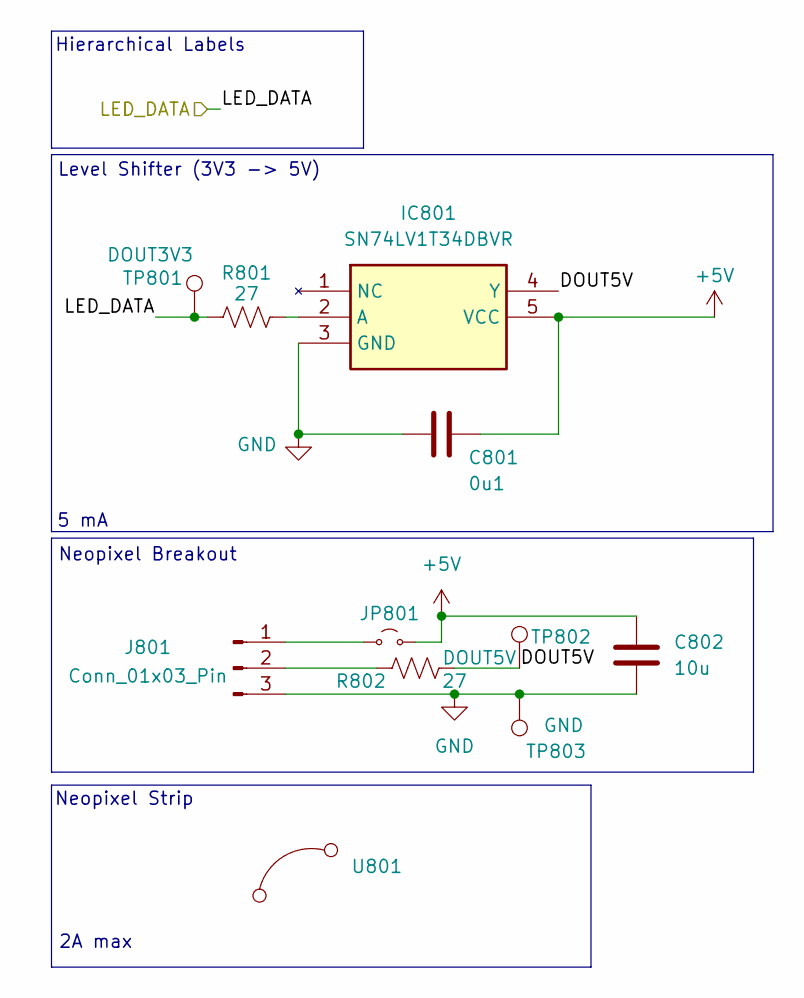
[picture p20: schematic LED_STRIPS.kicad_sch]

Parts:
C801: 0u1; C_0603_1608Metric
C802: 10u; C_0603_1608Metric
IC801: SN74LV1T34DBVR; SOT95P280X145-5N; Mouser Part Number 595-SN74LV1T34DBVR
J801: Conn_01x03_Pin; PinHeader_1x03_P2.54mm_Vertical
JP801: Jumper_2_Small_Bridged; SolderJumper-2_P1.3mm_Open_TrianglePad1.0x1.5mm
R801, R802: 27; R_0603_1608Metric
TP801: DOUT3V3; bettertestpoint2
TP802: DOUT5V; bettertestpoint2
TP803: GND; bettertestpoint2
U801: (no value)

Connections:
+5V: C801.2, C802.1, IC801.5 (VCC), JP801.2 (B); also elsewhere on the board
/LED Strip/DOUT5V: IC801.4 (Y), R802.2, TP802.1
/LED Strip/LED_DATA: R801.1, TP801.1; also elsewhere on the board
GND: C801.1, C802.2, IC801.3 (GND), J801.3, TP803.1; also elsewhere on the board
unnamed: IC801.2 (A), R801.2
unnamed: J801.1, JP801.1 (A)
unnamed: J801.2, R802.1

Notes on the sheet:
Neopixel Breakout
5 mA
Neopixel Strip
2A max
Hierarchical Labels
Level Shifter (3V3 -> 5V)

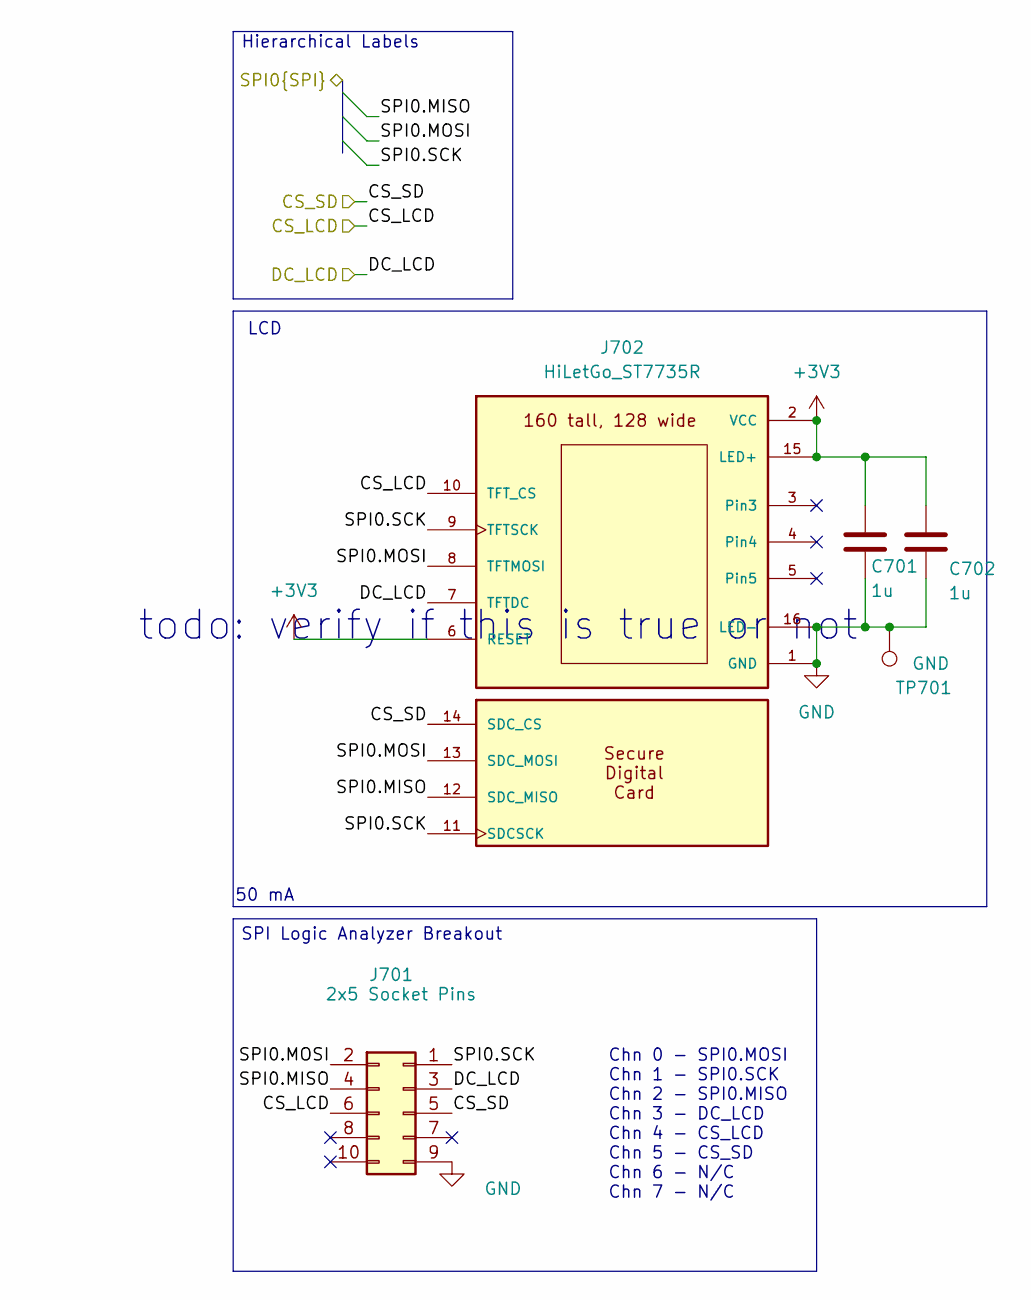
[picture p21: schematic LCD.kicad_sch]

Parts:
C701, C702: 1u; C_0603_1608Metric
J701: 2x5 Socket Pins; logic_analyzer_slot_2x5_2.54mm
J702: HiLetGo_ST7735R; hiletgo_st7735r
TP701: GND; bettertestpoint2

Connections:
+3V3: C701.1, C702.1, J702.2 (VCC), J702.6 (RESET), J702.15 (LED+); also elsewhere on the board
/LCD/CS_LCD: J701.6, J702.10 (TFT_CS); also elsewhere on the board
/LCD/CS_SD: J701.5, J702.14 (SDC_CS); also elsewhere on the board
/LCD/DC_LCD: J701.3, J702.7 (TFTDC); also elsewhere on the board
/LCD/SPI0.MISO: J701.4, J702.12 (SDC_MISO); also elsewhere on the board
/LCD/SPI0.MOSI: J701.2, J702.8 (TFTMOSI), J702.13 (SDC_MOSI); also elsewhere on the board
/LCD/SPI0.SCK: J701.1, J702.9 (TFTSCK), J702.11 (SDCSCK); also elsewhere on the board
GND: C701.2, C702.2, J701.9, J702.1 (GND), J702.16 (LED-), TP701.1; also elsewhere on the board

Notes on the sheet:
todo: verify if this is true or not
LCD
SPI Logic Analyzer Breakout
50 mA
Hierarchical Labels
Chn 0 - SPI0.MOSI Chn 1 - SPI0.SCK Chn 2 - SPI0.MISO Chn 3 - DC_LCD Chn 4 - CS_LCD Chn 5 - CS_SD Chn 6 - N/C Chn 7 - N/C

Board: 2 copper layers, 121 parts (0 on the bottom side), 85 nets, no tracks yet.

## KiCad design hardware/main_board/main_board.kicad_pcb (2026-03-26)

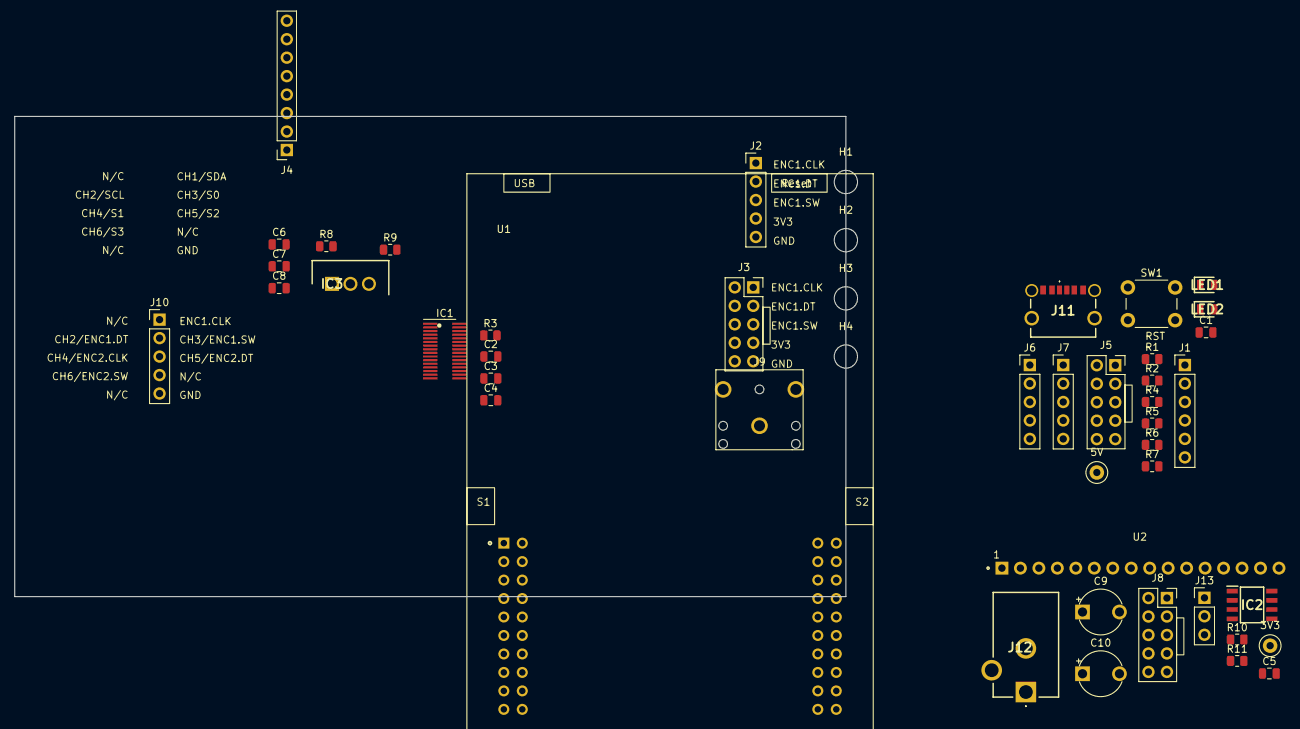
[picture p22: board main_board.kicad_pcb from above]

Board: 2 copper layers, 114.3 x 66.0 mm, 48 parts (0 on the bottom side), 41 nets, no tracks yet.

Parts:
C1: 0.47uF; C_0805_2012Metric
C2, C6, C8: 1u; C_0805_2012Metric
C3: 10nF; C_0805_2012Metric
C4: 10uF; C_0805_2012Metric
C5: 0.1uF; C_0805_2012Metric
C7: 0u33; C_0805_2012Metric
C9, C10: 4u7; CP_Radial_Tantal200mil
H1, H2, H3, H4: MountingHole; MountingHole_3.2mm_M3
IC1: M0G3507QDGS32RQ1; generic_VSSOP_0.5mm
IC2: LM4890M_NOPB; ti_LM4890M_NOPB
IC3: LM2937ET-3.3_NOPB; TO254P470X1028X1955-3P
J1: Conn_01x06_Pin; PinHeader_1x06_P2.54mm_Vertical
J2, J10: Conn_01x04_Pin; PinHeader_1x05_P2.54mm_Vertical
J3, J5, J8: 2x5 Socket Pins; logic_analyzer_slot_2x5_2.54mm
J4: 1x8 Male Pins; PinSocket_1x08_P2.54mm_Vertical
J6, J7: Conn_01x05_Pin; PinHeader_1x05_P2.54mm_Vertical
J9: AudioJack; Jack_3.5mm_CUI_SJ1-3523N_Horizontal
J11: UJC-H-G-SMT-1-P6-TR; UJCHGSMT1P6TR
J12: 373
J13: Conn_01x03_Pin; PinHeader_1x03_P2.54mm_Vertical
LED1: RUN_LED; LEDC2012X40N
LED2: PWR_LED; LEDC2012X40N
R1, R2, R6, R7: 10k; R_0805_2012Metric
R3: 47k; R_0805_2012Metric
R4, R5: 470; R_0805_2012Metric
R8, R9: 20k; R_0805_2012Metric
R10, R11: 5k1; R_0805_2012Metric
SW1: RST; SW_PUSH_6mm
TP1: 5V; bettertestpoint2
TP2: 3V3; bettertestpoint2
U1: LP-MSPM0G3507; ti_LP_MSPM0G3507
U2: HiLetGo_ST7735R; hiletgo_st7735r

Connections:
+3V3: C4.1, C5.1, C10.1, IC1.7 (VDD), IC3.3 (OUTPUT), J1.5, J2.1, J6.4, J7.4, J10.1, R1.2, R2.2, R3.1, R5.1, R6.2, R7.2, TP2.1, U1.J1_1 (+3.3V), U2.2 (VCC), U2.6 (RESET), U2.15 (LED+)
+5V: C6.2, C9.1, IC2.6 (VDD), IC3.1 (INPUT), J4.1, J11.A9 (VBUS), J11.B9 (VBUS), TP1.1, U1.J3_1 (+VBUS)
+5VD: J12.1, J13.2
/Audio IO/DAC_OUT: C7.1, IC1.22 (PA15/A1_0/DACOUT)
/Audio IO/UART1_RX: IC1.16 (PA9/RTC_OUT/CLK_OUT), J10.2
/Audio IO/UART1_TX: IC1.15 (PA8), J10.3
/Encoders & Buttons/ENC1.CLK: IC1.1 (PA26/A0_1), J6.1, J8.1
/Encoders & Buttons/ENC1.DT: IC1.2 (PA27/RTC_OUT/A0_0), J6.2, J8.4
/Encoders & Buttons/ENC1.SW: IC1.32 (PA25/A0_2), J6.3, J8.3, R6.1
/Encoders & Buttons/ENC2.CLK: IC1.24 (PA17/A1_2), J7.1, J8.6
/Encoders & Buttons/ENC2.DT: IC1.29 (PA22/CLK_OUT/A0_7), J7.2, J8.5
/Encoders & Buttons/ENC2.SW: IC1.31 (PA24/A0_3), J7.3, J8.8, R7.1
/LCD/CS_LCD: IC1.10 (PA3/LFXIN), J5.5, U2.10 (TFT_CS)
/LCD/CS_SD: IC1.9 (PA2/ROSC), J5.7, U2.14 (SDC_CS)
/LCD/LCD_DC: IC1.14 (PA7/CLK_OUT), J5.6, U2.7 (TFTDC)
/LCD/SPI0.MISO: IC1.11 (PA4/LFCLK_IN/LFXOUT), J5.3, U2.12 (SDC_MISO)
/LCD/SPI0.MOSI: IC1.12 (PA5/HFXIN/FCC_IN), J5.1, U2.8 (TFTMOSI), U2.13 (SDC_MOSI)
/LCD/SPI0.SCK: IC1.13 (PA6/HFCLK_IN/HFXOUT), J5.4, U2.9 (TFTSCK), U2.11 (SDCSCK)
/MCU/BSL_INVOKE: IC1.25 (PA18/A1_3), J1.1
/MCU/I2C0.SCL: IC1.5 (PA1), J3.4, J4.3, R1.1
/MCU/I2C0.SDA: IC1.4 (PA0), J3.1, J4.2, R2.1
/MCU/NRST: C3.1, IC1.6 (NRST), J1.4, R3.2, SW1.2
/MCU/S0: IC1.19 (PA12/FCC_IN), J3.3, J4.4
/MCU/S1: IC1.20 (PA13), J3.6, J4.5
/MCU/S2: IC1.21 (PA14/CLK_OUT/A0_12), J3.5, J4.6
/MCU/S3: IC1.23 (PA16/A1_1/FCC_IN), J3.8, J4.7
/MCU/SWCLK: IC1.27 (PA20/SWCLK), J1.2
/MCU/SWDIO: IC1.26 (PA19/SWDIO), J1.3
/MCU/UART0_RX: IC1.18 (PA11), J2.2
/MCU/UART0_TX: IC1.17 (PA10/CLK_OUT), J2.3
GND: C1.2, C2.1, C3.2, C4.2, C5.2, C6.1, C8.2, C9.2, C10.2, IC1.8 (VSS), IC1.28 (PA21/A1_7/VREF-), IC2.1 (~SHUTDOWN), IC2.7 (GND), IC3.2 (GND), J1.6, J2.4, J3.9, J4.8, J5.9, J6.5, J7.5, J8.9, J9.S (sleeve), J10.4, J11.A12 (GND), J11.B12 (GND), J12.3, J13.3, LED1.1 (K), LED2.1 (K), R10.2, R11.2, SW1.1, U1.J2_1 (GND), U1.J3_2 (GND), U2.1 (GND), U2.16 (LED-)
unnamed: C7.2, R8.1
unnamed: C2.2, IC1.30 (PA23/VREF+)
unnamed: C1.1, IC1.3 (VCORE)
unnamed: C8.1, IC2.2 (BYPASS), IC2.3 (+IN)
unnamed: IC2.4 (-IN), R8.2, R9.1
unnamed: IC2.5 (VO_1), J9.R (ring), J9.T (tip), R9.2
unnamed: J11.A5 (CC1), R11.1
unnamed: J11.B5 (CC2), R10.1
unnamed: LED1.2 (A), R4.2
unnamed: LED2.2 (A), R5.2

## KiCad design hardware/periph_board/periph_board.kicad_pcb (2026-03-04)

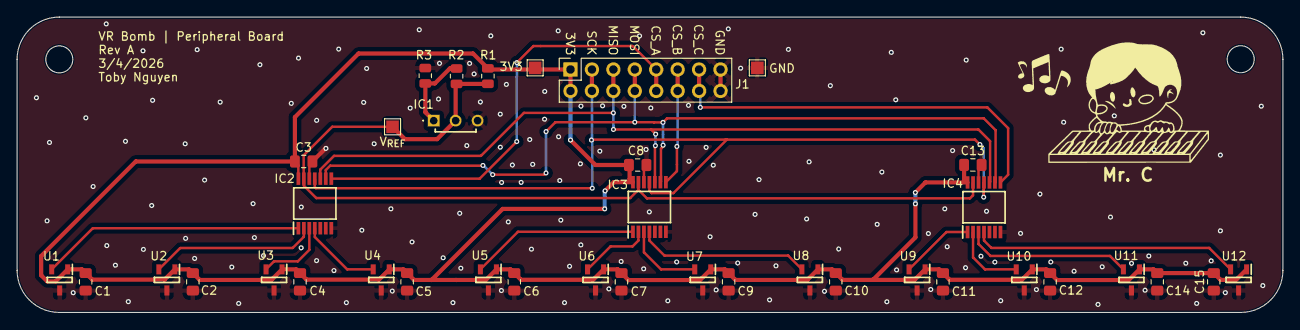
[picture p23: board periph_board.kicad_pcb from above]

Board: 2 copper layers, 150.0 x 35.0 mm, 40 parts (0 on the bottom side), 22 nets.

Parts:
C1, C2, C3, C4, C5, C6, C7, C8, C9, C10, C11, C12, C13, C14, C15: 1u; C_0805_2012Metric_Pad1.18x1.45mm_HandSolder
H1, H2: MountingHole; MountingHole_3.2mm_M3
IC1: LM4041CILPR
IC2, IC3, IC4: MCP3204T-CI_ST; SOP65P640X120-14N
J1: 2x8 Male Pins; PinSocket_2x08_P2.54mm_Vertical
R1, R2, R3: R_US; R_0805_2012Metric
TP1: 3V3; betterTestPoint_Pad_1.5x1.5mm
TP2: V_{REF}; betterTestPoint_Pad_1.5x1.5mm
TP3: GND; betterTestPoint_Pad_1.5x1.5mm
U1, U2, U3, U4, U5, U6, U7, U8, U9, U10, U11, U12: AH49HNTR-G1; SOT95P282X145-3N

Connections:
+3V3: C1.2, C2.2, C3.1, C4.2, C5.2, C6.2, C7.2, C8.1, C9.2, C10.2, C11.2, C12.2, C13.1, C14.2, C15.2, IC2.14 (VDD), IC3.14 (VDD), IC4.14 (VDD), J1.1, J1.2, R1.1, TP1.1, U1.1 (VCC), U2.1 (VCC), U3.1 (VCC), U4.1 (VCC), U5.1 (VCC), U6.1 (VCC), U7.1 (VCC), U8.1 (VCC), U9.1 (VCC), U10.1 (VCC), U11.1 (VCC), U12.1 (VCC)
/CS_{A}: IC2.8 (~CS/SHDN), J1.9, J1.10
/CS_{B}: IC3.8 (~CS/SHDN), J1.11, J1.12
/CS_{C}: IC4.8 (~CS/SHDN), J1.13, J1.14
/HALL_ARR_1/CH0: IC2.1 (CH0), U1.2 (OUT)
/HALL_ARR_1/CH1: IC2.2 (CH1), U2.2 (OUT)
/HALL_ARR_1/CH2: IC2.3 (CH2), U3.2 (OUT)
/HALL_ARR_1/CH3: IC2.4 (CH3), U4.2 (OUT)
/HALL_ARR_2/CH0: IC3.1 (CH0), U5.2 (OUT)
/HALL_ARR_2/CH1: IC3.2 (CH1), U6.2 (OUT)
/HALL_ARR_2/CH2: IC3.3 (CH2), U7.2 (OUT)
/HALL_ARR_2/CH3: IC3.4 (CH3), U8.2 (OUT)
/HALL_ARR_3/CH0: IC4.1 (CH0), U9.2 (OUT)
/HALL_ARR_3/CH1: IC4.2 (CH1), U10.2 (OUT)
/HALL_ARR_3/CH2: IC4.3 (CH2), U11.2 (OUT)
/HALL_ARR_3/CH3: IC4.4 (CH3), U12.2 (OUT)
/MISO: IC2.10 (DOUT), IC3.10 (DOUT), IC4.10 (DOUT), J1.5, J1.6
/MOSI: IC2.9 (DIN), IC3.9 (DIN), IC4.9 (DIN), J1.7, J1.8
/SCK: IC2.11 (CLK), IC3.11 (CLK), IC4.11 (CLK), J1.3, J1.4
/V_{REF}: IC1.2, IC2.13 (VREF), IC3.13 (VREF), IC4.13 (VREF), R1.2, R2.1, TP2.1
GND: C1.1, C2.1, C3.2, C4.1, C5.1, C6.1, C7.1, C8.2, C9.1, C10.1, C11.1, C12.1, C13.2, C14.1, C15.1, IC1.3, IC2.7 (DGND), IC2.12 (AGND), IC3.7 (DGND), IC3.12 (AGND), IC4.7 (DGND), IC4.12 (AGND), J1.15, J1.16, R3.2, TP3.1, U1.3 (GND), U2.3 (GND), U3.3 (GND), U4.3 (GND), U5.3 (GND), U6.3 (GND), U7.3 (GND), U8.3 (GND), U9.3 (GND), U10.3 (GND), U11.3 (GND), U12.3 (GND)
unnamed: IC1.1, R2.2, R3.1

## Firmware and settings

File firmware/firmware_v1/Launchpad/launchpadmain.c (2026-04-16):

// Lab7Main.c
// Runs on MSPM0G3507
// Lab 7
// Your name
// Last Modified: January 12, 2026

// #include "../inc/ADC1.h"
#include "../inc/Clock.h"
#include "../inc/LaunchPad.h"
#include "../inc/ST7735.h"
// #include "../inc/Texas.h"
#include "../inc/Timer.h"
#include <stdint.h>
#include <stdio.h>
#include <ti/devices/msp/msp.h>

#include "../lib/myUART.h"


// ****note to ECE319K students****
// the data sheet says the ADC does not work when clock is 80 MHz
// however, the ADC seems to work on my boards at 80 MHz
// I suggest you try 80MHz, but if it doesn't work, switch to 40MHz
void PLL_Init(void) { // set phase lock loop (PLL)
  // Clock_Init40MHz(); // run this line for 40MHz
  Clock_Init80MHz(0); // run this line for 80MHz
}

// // implement this function
// void OutFix(uint32_t n){
// // resolution is 0.001cm
// // n is integer 0 to 2000
// // output to ST7735 0.000cm to 2.000cm
//  // write this
// }

// // do not use this function for your final lab solution
// // it is added just to show you how SLOW floating point is on a Cortex M0+
// void FloatOutFix(float x){
// // resolution cm
// // x is integer 0 to 2.000
// // output to ST7735 0.000cm to 2.000cm
//   printf("d=%f cm   ",x);  // floating point output
// }

// uint32_t Data;        // 12-bit ADC
// uint32_t Position;    // 32-bit fixed-point 0.001 cm
// float FloatPosition;  // 32-bit floating-point cm
//  // define a semaphore
// uint32_t startTime,stopTime;
// uint32_t
// Offset,ADCtime,Converttime,FloatConverttime,OutFixtime,FloatOutFixtime; // in
// bus cycles uint32_t Time;
// // use main1 if you do not have a voltmeter
// // use main1 to test slidepot interface
// // connect slidepot pin 2 to ADC1 channel 5, PB18
// // Open TExaSdisplay and see slidepot pin2 go from 0 to 3.3V

// --------------- TEST CODE FOR 445L ---------------------
// Test analog mux selection of hall effect, 2 hall effect sensors are actually
// attached for testing purposes

int main(void) { // main1
  __disable_irq();
  PLL_Init(); // set bus speed
  LaunchPad_Init();
  // TExaS_Init(ADC1, 5, 0); // ADC1 channel 5, PB18, slidepot
  // ST7735_InitR(INITR_REDTAB);
  __enable_irq();

  // ST7735_FillScreen(ST7735_BLACK);

  while (1) {
    // ST7735_OutUDec4(i);
    static uint32_t i = 0;
    if (i > 15)
      i = 0;

    // GPIOB->DOUT31_0 = 0;

    switch (i) {
    case 0:
      GPIOB->DOUT31_0 = 0x000; // All off
      break;
    case 1:
      GPIOB->DOUT31_0 = 0x001; // PB0
      break;
    case 2:
      GPIOB->DOUT31_0 = 0x040; // PB6
      break;
    case 3:
      GPIOB->DOUT31_0 = 0x041; // PB6, PB0
      break;
    case 4:
      GPIOB->DOUT31_0 = 0x080; // PB7
      break;
    case 5:
      GPIOB->DOUT31_0 = 0x081; // PB7, PB0
      break;
    case 6:
      GPIOB->DOUT31_0 = 0x0C0; // PB7, PB6
      break;
    case 7:
      GPIOB->DOUT31_0 = 0x0C1; // PB7, PB6, PB0
      break;
    case 8:
      GPIOB->DOUT31_0 = 0x100; // PB8
      break;
    case 9:
      GPIOB->DOUT31_0 = 0x101; // PB8, PB0
      break;
    case 10:
      GPIOB->DOUT31_0 = 0x140; // PB8, PB6
      break;
    case 11:
      GPIOB->DOUT31_0 = 0x141; // PB8, PB6, PB0
      break;
    case 12:
      GPIOB->DOUT31_0 = 0x180; // PB8, PB7
      break;
    case 13:
      GPIOB->DOUT31_0 = 0x181; // PB8, PB7, PB0
      break;
    case 14:
      GPIOB->DOUT31_0 = 0x1C0; // PB8, PB7, PB6
      break;
    case 15:
      GPIOB->DOUT31_0 = 0x1C1; // PB8, PB7, PB6, PB0
      break;
    }

    i++;

    // Simple wait
    for (int j = 0; j < 100000; j++) {
      __asm("NOP");
    }
  }
}
// // if you have a voltmeter/scope,
// // use the voltmeter/scope see slidepot pin2 go from 0 to 3.3V

// // use main2 to test ADCinit and ADCin functions
// // connect slidepot pin 2 to PB18 ADC1
// // Data should go from 0 to 4095
// // ADCtime is the time to execute ADCin in bus cycles
// // use main2 to calibrate the system fill in 5 points in Calibration.xls
// //    determine constants k1 k2 to fit Position=(k1*Data)>>12 + k2
// int main2(void){ // main2
//   __disable_irq();
//   PLL_Init(); // set bus speed
//   LaunchPad_Init();
//   SysTick->LOAD = 0xFFFFFF;    // max
//   SysTick->VAL = 0;            // any write to current clears it
//   SysTick->CTRL = 0x00000005;  // enable SysTick with core clock
//   startTime = SysTick->VAL;
//   stopTime = SysTick->VAL;
//   Offset = (startTime-stopTime)&0x0FFFFFF; // in bus cycles to perform time
//   measurement ADCinit(); //ADC1 channel 5, PB18, slidepot while(1){
//     startTime = SysTick->VAL;
//     Data = ADCin();  // sample ADC1 channel 5, PB18, slidepot
//     stopTime = SysTick->VAL;
//     ADCtime = ((startTime-stopTime)&0x0FFFFFF)-Offset; // in bus cycles
//   }
// }

// // use main3 to test Convert functions
// // connect slidepot pin 2 to PB18
// // Data should go from 0 to 4095
// // Position should go from 0 to 2000
// // Use main3 to take another 5 measurements to determine accuracy
// // truth is your eyes and the cursor on your slide pot
// // measurement is the Position variable
// // Converttime is the time to execute Convert in bus cycles
// int main3(void){ // main3
//   __disable_irq();
//   PLL_Init(); // set bus speed
//   LaunchPad_Init();
//   SysTick->LOAD = 0xFFFFFF;    // max
//   SysTick->VAL = 0;            // any write to current clears it
//   SysTick->CTRL = 0x00000005;  // enable SysTick with core clock
//   startTime = SysTick->VAL;
//   stopTime = SysTick->VAL;
//   Offset = (startTime-stopTime)&0x0FFFFFF; // in bus cycles to perform time
//   measurement ADCinit(); //PB18 = ADC0 channel 5, slidepot while(1){
//     Data = ADCin();  // sample 12-bit ADC0 channel 5, slidepot
//     startTime = SysTick->VAL;
//     Position = Convert(Data);
//     stopTime = SysTick->VAL;
//     Converttime = ((startTime-stopTime)&0x0FFFFFF)-Offset; // in bus cycles
//     startTime = SysTick->VAL;
//     FloatPosition = FloatConvert(Data);
//     stopTime = SysTick->VAL;
//     FloatConverttime = ((startTime-stopTime)&0x0FFFFFF)-Offset; // in bus
//     cycles
//   }
// }

// // use main4 to test OutFix functions
// // connect slidepot pin 2 to PB18
// // Data should go from 0 to 4095
// // Position should go from 0 to 2000
// // LCD should show 0.000cm to 2.000 cm
// // OutFixtime is the time to execute OutFix in bus cycles
// int main4(void){ // main4
//   __disable_irq();
//   PLL_Init(); // set bus speed
//   LaunchPad_Init();
//   ST7735_InitPrintf(INITR_REDTAB); // INITR_REDTAB for AdaFruit,
//   INITR_BLACKTAB for HiLetGo ST7735_FillScreen(ST7735_BLACK); SysTick->LOAD =
//   0xFFFFFF;    // max SysTick->VAL = 0;            // any write to current
//   clears it SysTick->CTRL = 0x00000005;  // enable SysTick with core clock
//   startTime = SysTick->VAL;
//   stopTime = SysTick->VAL;
//   Offset = (startTime-stopTime)&0x0FFFFFF; // in bus cycles to perform time
//   measurement ADCinit(); //PB18 = ADC0 channel 5, slidepot while(1){
//     ST7735_SetCursor(0,0); // top left
//     Data = ADCin();  // sample 12-bit ADC0 channel 5, slidepot
//     Position = Convert(Data);
//     FloatPosition = FloatConvert(Data);
//     startTime = SysTick->VAL;
//     OutFix(Position);
//     stopTime = SysTick->VAL;
//     OutFixtime = ((startTime-stopTime)&0x0FFFFFF)-Offset; // in bus cycles
//     ST7735_SetCursor(0,1); // second row
//     startTime = SysTick->VAL;
//     FloatOutFix(FloatPosition);
//     stopTime = SysTick->VAL;
//     FloatOutFixtime = ((startTime-stopTime)&0x0FFFFFF)-Offset; // in bus
//     cycles Clock_Delay1ms(100);
//   }
// }
// // sampling frequency is 30 Hz
// void TIMG12_IRQHandler(void){
//   if((TIMG12->CPU_INT.IIDX) == 1){ // this will acknowledge
//     GPIOB->DOUTTGL31_0 = GREEN; // toggle PB27 (minimally intrusive
//     debugging) GPIOB->DOUTTGL31_0 = GREEN; // toggle PB27 (minimally
//     intrusive debugging) Time++;
//     // sample 12-bit ADC0 channel 5, slidepot
//     // store data into mailbox
//     // set the semaphore
//     GPIOB->DOUTTGL31_0 = GREEN; // toggle PB27 (minimally intrusive
//     debugging)
//   }
// }
// uint8_t TExaS_LaunchPadLogicPB27PB26(void){
//   return (0x80|((GPIOB->DOUT31_0>>26)&0x03));
// }
// // use main5 for final system
// // use scope or logic analyzer to verify real time samples
// // option 1) remove call to TExaS_Init and use a real scope on PB27
// // option 2) use TExaS logic analyzer
// int main5(void){ // main5
//   __disable_irq();
//   PLL_Init(); // set bus speed
//   LaunchPad_Init();
//   ST7735_InitPrintf(INITR_REDTAB); // INITR_REDTAB for AdaFruit,
//   INITR_BLACKTAB for HiLetGo ST7735_FillScreen(ST7735_BLACK); ADCinit();
//   //PB18 = ADC1 channel 5, slidepot
//   TExaS_Init(0,0,&TExaS_LaunchPadLogicPB27PB26); // PB27 and PB26
//   ST7735_PlotClear(0,2000);
//     // initialize interrupts on TimerG12 at 30 Hz

//   // initialize semaphore

//   Time = 0;
//   __enable_irq();
//   while(1){
//       // write this

//     // wait for semaphore
//     // clear the semaphore
//     GPIOB->DOUTTGL31_0 = RED; // toggle PB26 (minimally intrusive debugging)
//     // toggle red LED2 on Port B, PB26
//      // convert Data to Position
//      // move cursor to top
//     // display distance in top row OutFix

//     Time++;
//     if((Time%15)==0){
//       ST7735_PlotPoint(Position);
//       ST7735_PlotNextErase(); // data plotted at about 2 Hz
//     }
//   }
// }

// // use main6 to study Central Limit Theorem
// uint32_t Histogram[64]; // probability mass function
// uint32_t Center,SAC;
// #define SCALE 2000
// int main6(void){ // main6
//   __disable_irq();
//   PLL_Init(); // set bus speed
//   LaunchPad_Init();
//   ST7735_InitPrintf(INITR_REDTAB); // INITR_REDTAB for AdaFruit,
//   INITR_BLACKTAB for HiLetGo ST7735_FillScreen(ST7735_BLACK); ADCinit();
//   //PB18 = ADC1 channel 5, slidepot SAC = 1; while(1){int i; uint32_t d,sum;
//     sum = 0;
//     for(int j=0; j<100; j++){
//       sum += ADCin();  // sample 12-bit ADC0 channel 5, slidepot
//     }
//     Center = sum/100; // averaging
//     for(i=0; i<64; i++) Histogram[i] = 0; // clear
//     for(i=0; i<200; i++){
//       sum = 0;
//       for(int j=0; j<SAC; j++){
//         sum += ADCin();  // sample 12-bit ADC0 channel 5, slidepot
//       }
//       Data = sum/SAC; // averaging
//       if(Data<Center-32){
//          Histogram[0]++;
//       }else if(Data>=Center+32){
//          Histogram[63]++;
//       }else{
//         d = Data-Center+32;
//         Histogram[d]++;
//       }
//     }
//     ST7735_PlotClear(0,100);
//     ST7735_SetCursor(0,0);
//     printf("SAC=%3u,Center=%4u",SAC,Center);
//     for(i=0; i<63; i++){
//       if(Histogram[i]>99) Histogram[i]=99;
//       ST7735_PlotBar(Histogram[i]);
//       ST7735_PlotNext();
//       ST7735_PlotBar(Histogram[i]);
//       ST7735_PlotNext();
//     }
//     while(LaunchPad_InS2()==0x00040000){}; // wait for release
//     while(LaunchPad_InS2()==0){};          // wait for touch
//     SAC = SAC<<1;
//     if(SAC >= 256) SAC = 1;
//   }
// }

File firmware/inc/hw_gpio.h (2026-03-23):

//*****************************************************************************
//
// hw_gpio.h - Defines and Macros for GPIO hardware.
//
// Copyright (c) 2005-2014 Texas Instruments Incorporated.  All rights reserved.
// Software License Agreement
// 
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
//   Redistributions of source code must retain the above copyright
//   notice, this list of conditions and the following disclaimer.
// 
//   Redistributions in binary form must reproduce the above copyright
//   notice, this list of conditions and the following disclaimer in the
//   documentation and/or other materials provided with the  
//   distribution.
// 
//   Neither the name of Texas Instruments Incorporated nor the names of
//   its contributors may be used to endorse or promote products derived
//   from this software without specific prior written permission.
// 
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
// This is part of revision 2.1.0.12573 of the Tiva Firmware Development Package.
//
//*****************************************************************************

#ifndef __HW_GPIO_H__
#define __HW_GPIO_H__

//*****************************************************************************
//
// The following are defines for the GPIO register offsets.
//
//*****************************************************************************
#define GPIO_O_DATA             0x00000000  // GPIO Data
#define GPIO_O_DIR              0x00000400  // GPIO Direction
#define GPIO_O_IS               0x00000404  // GPIO Interrupt Sense
#define GPIO_O_IBE              0x00000408  // GPIO Interrupt Both Edges
#define GPIO_O_IEV              0x0000040C  // GPIO Interrupt Event
#define GPIO_O_IM               0x00000410  // GPIO Interrupt Mask
#define GPIO_O_RIS              0x00000414  // GPIO Raw Interrupt Status
#define GPIO_O_MIS              0x00000418  // GPIO Masked Interrupt Status
#define GPIO_O_ICR              0x0000041C  // GPIO Interrupt Clear
#define GPIO_O_AFSEL            0x00000420  // GPIO Alternate Function Select
#define GPIO_O_DR2R             0x00000500  // GPIO 2-mA Drive Select
#define GPIO_O_DR4R             0x00000504  // GPIO 4-mA Drive Select
#define GPIO_O_DR8R             0x00000508  // GPIO 8-mA Drive Select
#define GPIO_O_ODR              0x0000050C  // GPIO Open Drain Select
#define GPIO_O_PUR              0x00000510  // GPIO Pull-Up Select
#define GPIO_O_PDR              0x00000514  // GPIO Pull-Down Select
#define GPIO_O_SLR              0x00000518  // GPIO Slew Rate Control Select
#define GPIO_O_DEN              0x0000051C  // GPIO Digital Enable
#define GPIO_O_LOCK             0x00000520  // GPIO Lock
#define GPIO_O_CR               0x00000524  // GPIO Commit
#define GPIO_O_AMSEL            0x00000528  // GPIO Analog Mode Select
#define GPIO_O_PCTL             0x0000052C  // GPIO Port Control
#define GPIO_O_ADCCTL           0x00000530  // GPIO ADC Control
#define GPIO_O_DMACTL           0x00000534  // GPIO DMA Control
#define GPIO_O_SI               0x00000538  // GPIO Select Interrupt
#define GPIO_O_DR12R            0x0000053C  // GPIO 12-mA Drive Select
#define GPIO_O_WAKEPEN          0x00000540  // GPIO Wake Pin Enable
#define GPIO_O_WAKELVL          0x00000544  // GPIO Wake Level
#define GPIO_O_WAKESTAT         0x00000548  // GPIO Wake Status
#define GPIO_O_PP               0x00000FC0  // GPIO Peripheral Property
#define GPIO_O_PC               0x00000FC4  // GPIO Peripheral Configuration

//*****************************************************************************
//
// The following are defines for the bit fields in the GPIO_O_IM register.
//
//*****************************************************************************
#define GPIO_IM_DMAIME          0x00000100  // GPIO uDMA Done Interrupt Mask
                                            // Enable
#define GPIO_IM_GPIO_M          0x000000FF  // GPIO Interrupt Mask Enable
#define GPIO_IM_GPIO_S          0

//*****************************************************************************
//
// The following are defines for the bit fields in the GPIO_O_RIS register.
//
//*****************************************************************************
#define GPIO_RIS_DMARIS         0x00000100  // GPIO uDMA Done Interrupt Raw
                                            // Status
#define GPIO_RIS_GPIO_M         0x000000FF  // GPIO Interrupt Raw Status
#define GPIO_RIS_GPIO_S         0

//*****************************************************************************
//
// The following are defines for the bit fields in the GPIO_O_MIS register.
//
//*****************************************************************************
#define GPIO_MIS_DMAMIS         0x00000100  // GPIO uDMA Done Masked Interrupt
                                            // Status
#define GPIO_MIS_GPIO_M         0x000000FF  // GPIO Masked Interrupt Status
#define GPIO_MIS_GPIO_S         0
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

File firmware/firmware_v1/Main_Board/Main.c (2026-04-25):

// Main.c
#include <stdint.h>
#include <stdio.h>

#include "../lib/ti_msp_dl_config.h"

#include "../inc/Clock.h"
#include "../inc/LaunchPad.h"
#include "../inc/Timer.h"
// #include "../inc/ADC1.h"
// #include "../inc/ST7735.h"
// #include "../inc/UART.h"
// #include "../lib/myUART.h"
// #include "../lib/ledStrip.h"
// #include "../inc/I2C.h"
#include "../lib/I2CADC.h"
// #include "../inc/DAC.h"
#include "../inc/ST7735.h"
#include "../lib/encoder.h"
#include "../lib/display.h"

#include "../lib/Audio_DAC_DMA.h"
#include "../lib/encoder.h"
#include "../lib/synth.h"


#include "BoardConfig.h"

void PLL_Init(void) {
  // calls the correct clock function based on BoardConfig.h
  INIT_SYS_CLOCK();
}

void initHeart(void) {
  IOMUX->SECCFG.PINCM[LED_IOMUX] = 0x00000081;
  LED_PORT->DOE31_0 |= (1 << LED_PIN);
  TimerG0_IntArm(UINT16_MAX, 0, 0);
}

void toggleHeart(void) { LED_PORT->DOUTTGL31_0 = (1 << LED_PIN); }

void TIMG0_IRQHandler() { toggleHeart(); }

int main(void) {
  __disable_irq();
  Clock_Init80MHz(0);
  LaunchPad_Init();
  DAC0_Init();
  TimerG0_32kHz_EventArm();
  DMA_Init_CircularPingPong();
  initADC();
  __enable_irq();
  while (1) {
    Synth_Write_Buf();
  }
}

// int main2(void) {
//     __disable_irq();
//     Clock_Init80MHz(0);
//     LaunchPad_Init();
//     encoderInit();
//     initLCD();
//     __enable_irq();
//     resetMenu();
//   while (1) {
//         if (update_screen_type) {
//             update_screen_type = 0; 
//             if (menu_screen == 0) {
//                 resetMenu();
//                 drawMenu();
//             } else {
//                 drawSelectedInstrument();
//             }
//         }
//         if (update_menu) {
//             update_menu = 0;
//             drawMenu(); 
//         }
// }
// }

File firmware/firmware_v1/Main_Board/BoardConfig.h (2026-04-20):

// BoardConfig.h
#ifndef BOARDCONFIG_H
#define BOARDCONFIG_H

#include <ti/devices/msp/msp.h>

// =========================================================
// MASTER SWITCH: Uncomment the target you are compiling for
// =========================================================
#define TARGET_LAUNCHPAD
// #define TARGET_CUSTOM_CHIP

// =========================================================
// CONFIGURATION PROFILES
// =========================================================

#ifdef TARGET_LAUNCHPAD

    // --- Clock Setup ---
    #define INIT_SYS_CLOCK()    Clock_Init80MHz(0)

    // --- Mux Pins (GPIOB) ---
    #define MUX_PORT            GPIOB
    #define MUX_SEL0_PIN        20   // PB20
    #define MUX_SEL1_PIN        24   // PB24
    #define MUX_SEL2_PIN        3    // PB3
    #define MUX_SEL3_PIN        4    // PB4

    #define MUX_SEL0_IOMUX      PB20INDEX
    #define MUX_SEL1_IOMUX      PB24INDEX
    #define MUX_SEL2_IOMUX      PB3INDEX
    #define MUX_SEL3_IOMUX      PB4INDEX

    // --- Heartbeat LED (GPIOA) ---
    #define LED_PORT            GPIOA
    #define LED_PIN             16   // PA16
    #define LED_IOMUX           PA16INDEX

#elif defined(TARGET_CUSTOM_CHIP)

    // --- Clock Setup ---
    #define INIT_SYS_CLOCK()    Clock_Init80MHz_Internal()

    // --- Mux Pins (GPIOA) ---
    #define MUX_PORT            GPIOA
    #define MUX_SEL0_PIN        12   // PA12
    #define MUX_SEL1_PIN        13   // PA13
    #define MUX_SEL2_PIN        22   // PA22
    #define MUX_SEL3_PIN        16   // PA16

    #define MUX_SEL0_IOMUX      PA12INDEX
    #define MUX_SEL1_IOMUX      PA13INDEX
    #define MUX_SEL2_IOMUX      PA22INDEX
    #define MUX_SEL3_IOMUX      PA16INDEX

    // --- Heartbeat LED (GPIOA) ---
    #define LED_PORT            GPIOA
    #define LED_PIN             18   // PA18
    #define LED_IOMUX           PA18INDEX

#else
    #error "Please define a target board (TARGET_LAUNCHPAD or TARGET_CUSTOM_CHIP) in BoardConfig.h"
#endif

#endif // BOARDCONFIG_H

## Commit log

2026-03-04 Finished Rev A of peripheral PCB schematic/layout (need to find values for resistors lol). Added ECE445L lab docs
    [Datasheets.xlsx, HALL_ARR.kicad_sch, LM4041 Voltage Reference Design.xlsx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]
2026-03-06 MSPM0 Starter
    [MSPM0_Starter.kicad_pcb, MSPM0_Starter.kicad_sch]
2026-03-07 ece445l libraries added. moved mspm0 starter to /hw to /hardware with other files
    [MSPM0_Starter.kicad_pcb, MSPM0_Starter.kicad_sch, periph_board.kicad_pcb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]
2026-03-07 third peripheral board layout done
    [periph_board.kicad_pcb]
2026-03-08 finished periph board rev A. ready for order! added some more content to main board
    [AUDIO_IO.kicad_sch, ENCODERS_BUTTONS.kicad_sch, HALL_ARR.kicad_sch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]
2026-03-13 pls review pboard with i2c sensor
    [ENCODERS_BUTTONS.kicad_sch, LCD.kicad_sch, MCU.kicad_sch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]
2026-03-17 Created gerbers using kicad-jlcpcb-tools
    [periph_board-CuBottom.gbr, periph_board-CuTop.gbr, periph_board-EdgeCuts.gbr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]
2026-03-23 added 319k lab 7 to resources
    [Calibration.xls]
2026-03-23 fixed peripheral board dimensions to be compatible with 2.54 mm pitch protoboard for daisy chaining. deleted gerbers. added some more content to main board (wip)
    [AUDIO_IO.kicad_sch, ENCODERS_BUTTONS.kicad_sch, HALL_ARR.kicad_sch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]
2026-03-23 Jeffey try building this
    [Calibration.xls, LM4041 Voltage Reference Design.xlsx]
2026-03-25 reorganize lol
    [Calibration.xls]
2026-03-26 added lakshay suggestions to peripheral board. removed bypass jumper from main board audio amp. added led strip interface. added too many things to remember i forgor
    [AUDIO_IO.kicad_sch, ENCODERS_BUTTONS.kicad_sch, HALL_ARR.kicad_sch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]
2026-03-27 main board stuff. removed usbc for power. added level shifter for led logic signal. added lights for mux select signals. finished layout + pass DRC
    [AUDIO_IO.kicad_sch, ENCODERS_BUTTONS.kicad_sch, LCD.kicad_sch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]
2026-03-27 removed starter msp proj. fixed all 3d model paths (hopefully). added power led and changed MH to be 319k standoff compatible
    [MSPM0_Starter.kicad_pcb, MSPM0_Starter.kicad_sch, periph_board.kicad_sch]
2026-03-28 pcb review changes
    [AUDIO_IO.kicad_sch, LCD.kicad_sch, LED_STRIPS.kicad_sch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]
2026-03-30 added selection line LEDs to p board
    [periph_board.kicad_sch]
2026-03-30 Dimensioned correctly, need to reroute for hall effects
2026-03-31 changed level shifter. bunch of aesthetic changes. led resistors changed on main board. saving before nuke mouser.co.uk
    [AUDIO_IO.kicad_sch, LED_STRIPS.kicad_sch, MCU.kicad_sch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]
2026-03-31 finished everything except bom information. drc verification
    [AUDIO_IO.kicad_sch, HALL_ARR.kicad_sch, LED_STRIPS.kicad_sch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]
2026-03-31 fuck shit
    [AUDIO_IO.kicad_sch]
2026-04-09 led info
    [AUDIO_IO.kicad_sch, ENCODERS_BUTTONS.kicad_sch, LCD.kicad_sch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]
2026-04-09 up to date scheamtic
    [LED_STRIPS.kicad_sch]
2026-04-16 led chaser launchpad select lines
2026-04-18 Added launchpad/chip switch, switched main
    [Calibration.xls]
2026-04-18 wip led strip
2026-04-18 kys harddare
    [AUDIO_IO.kicad_sch, LED_STRIPS.kicad_sch, MCU.kicad_sch]
2026-04-18 added ti driver files for dma
2026-04-19 moved dma to its own file
2026-04-20 i2c and adc sampling working
2026-04-20 working ADC for all 60 keys
2026-04-20 spi. butchered main
    [MCU.kicad_sch]
2026-04-20 Modified SPI.c, REMOVED RESET PIN
2026-04-21 Previous commit broken? SPI.c with no reset
2026-04-21 Added DMA stuff currently working on
2026-04-21 Now linking whole lib folder, partially working DMA stuff
2026-04-21 fixed encoder init
2026-04-22 encoder and switch interrupt working
2026-04-22 Pingpong using driverlib works
2026-04-22 cleaned up main. please no more merge conflict. also added some dma stuff
2026-04-22 Starting timer control of DAC
2026-04-23 DMA and DAC working without driverlib
2026-04-23 working encoder and display
2026-04-23 Attack and release framework working
2026-04-28 rev2 coming soon ™️
    [AUDIO_IO.kicad_sch, ENCODERS_BUTTONS.kicad_sch, HALL_ARR.kicad_sch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]
2026-04-29 wrote most of electrical docs. picture test!
    [periph_board.kicad_sch]
2026-04-29 more readme i go bed
2026-04-29 color test
    [MCU.kicad_sch, main_boardv1.kicad_sch]
2026-04-30 new hardware
    [AUDIO_IO.kicad_sch, LED_STRIPS.kicad_sch, MCU.kicad_sch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]
2026-05-01 wired most of new hardware. need to reviist audio stuff
    [AUDIO_IO.kicad_sch, MCU.kicad_sch, PERIPHERAL_INT.kicad_sch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]
2026-05-03 more hardware
    [AUDIO_IO.kicad_sch, ENCODERS_BUTTONS.kicad_sch, LED_STRIPS.kicad_sch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]
2026-05-16 dubious hardware schematic 'done'. need to go back and revise passives and verify IC connections, esp the DAC. modified readme
    [AUDIO_IO.kicad_sch, LCD.kicad_sch, LED_STRIPS.kicad_sch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]
2026-05-16 long pcb image
2026-06-12 schematic sorta done? resized all RC packages to 0805
    [AUDIO_IO.kicad_sch, ENCODERS_BUTTONS.kicad_sch, LCD.kicad_sch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]
2026-06-18 resized all package to 0603
    [AUDIO_IO.kicad_sch, ENCODERS_BUTTONS.kicad_sch, LCD.kicad_sch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]
